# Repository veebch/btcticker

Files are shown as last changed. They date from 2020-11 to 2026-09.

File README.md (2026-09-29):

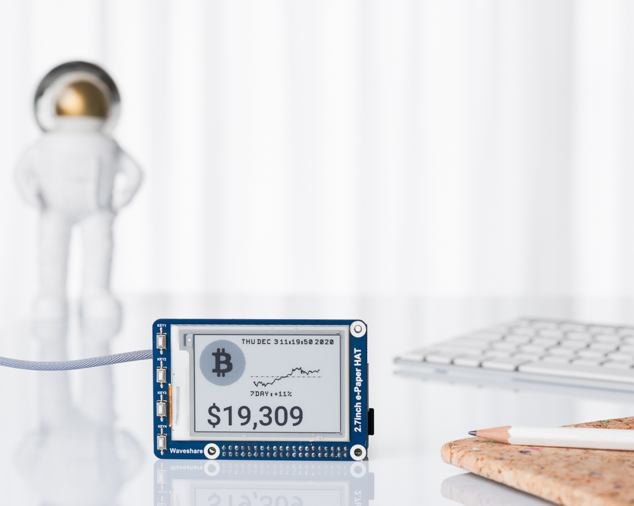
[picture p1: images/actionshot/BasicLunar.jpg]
Action Shot




# Cryptocurrency ePaper Ticker 

**(UPDATE: this all relies on the coingecko free api, and a full OS. If you just want to look at bitcoin prices, we have much simpler devices that involve minimal setup at [dirtboy.industries](https://shop.dirtboy.industries/search/btc))** if you prefer tinkering and/or non BTC stuff, read on...

An ePaper Cryptocurrency price ticker that runs as a Python script on a Raspberry Pi connected to a [Waveshare 2.7 inch monochrome ePaper display](https://www.waveshare.com/wiki/2.7inch_e-Paper_HAT). The script periodically (every 5 mins by default) takes data from CoinGecko and prints a summary to the ePaper. You can specify the exchange used for price info, as well as the currencies that your chosen coin's prices are in. 

A few minutes work gives you a desk ornament that will tastefully and unobtrusively monitor a coin's journey moonward.

(supports all coins/currencies/exchanges listed on [CoinGecko](https://api.coingecko.com/api/v3/coins/list))

# Getting started

## Prerequisites

These instructions work on both older Raspberry Pi OS releases (such as Bullseye) and newer ones (Bookworm, Trixie and later). Newer releases require Python packages installed with `pip` to live in a virtual environment, so the instructions use one on every version. They assume your Raspberry Pi is already connected to the Internet.

If you are using an original Pi Zero or Zero W, use the 32-bit Raspberry Pi OS Lite image (these boards cannot run the 64-bit version). A Zero 2 W can run either, and Lite is still recommended given the 512MB of RAM.

The script is set up to work for the V1 Waveshare 2.7in ePaper. If you are using V2 then see the note in btcticker.py about switching to V2.

If you are running the Pi headless, connect to your Raspberry Pi using `ssh`.

Connect to your ticker over ssh and update and install necessary packages 
```
sudo apt-get update
sudo apt-get install -y git python3-venv
sudo apt-get install -y python3-pil python3-numpy python3-matplotlib python3-spidev python3-gpiozero
sudo apt-get install -y python3-requests python3-babel python3-yaml
```

Enable spi (0=on 1=off)

```
sudo raspi-config nonint do_spi 0
```

Now clone the required software (Waveshare libraries and this script)

```
cd ~
git clone https://github.com/waveshare/e-Paper
git clone https://github.com/veebch/btcticker.git
```
Move to the `btcticker` directory, copy the example config to `config.yaml` and move the required part of the waveshare directory to the `btcticker` directory
```
cd ~/btcticker
cp config_example.yaml config.yaml
cp -r ~/e-Paper/RaspberryPi_JetsonNano/python/lib/waveshare_epd .
rm -rf ~/e-Paper
```

Create a virtual environment inside the `btcticker` directory. The `--system-site-packages` option lets it use the Python packages you just installed with apt (numpy, matplotlib, Pillow, requests, Babel, PyYAML, SPI and GPIO libraries), so pip only needs to install the one module that is not packaged for apt.
```
python3 -m venv --system-site-packages .venv
```
Install the required Python3 modules into the virtual environment
```
.venv/bin/pip install -r requirements.txt
```
You do not need to activate the virtual environment. Running `.venv/bin/python` uses it automatically. To test the ticker by hand:
```
.venv/bin/python btcticker.py
```

## Add Autostart

The command below fills in your own user name and home directory automatically, so it works whatever your user is called.

```
cat <<EOF | sudo tee /etc/systemd/system/btcticker.service
[Unit]
Description=btcticker
Wants=network-online.target
After=network-online.target

[Service]
ExecStart=$HOME/btcticker/.venv/bin/python -u $HOME/btcticker/btcticker.py
WorkingDirectory=$HOME/btcticker/
StandardOutput=inherit
StandardError=inherit
Restart=always
User=$USER

[Install]
WantedBy=multi-user.target
EOF
```
Now enable and start the service you just made
```  
sudo systemctl daemon-reload
sudo systemctl enable --now btcticker.service
```
To check it is running, or to see any errors:
```
systemctl status btcticker.service
journalctl -u btcticker.service -f
```
# Control via buttons

This only applies if you are going to control configuration via the buttons on the board.

The ePaper is slow. There is a lag of a few seconds between button press and a change to the display. 

Here's what each of the buttons do:
- Button 1: Cycle through the cryptocurrencies listed in config.yaml
- Button 2: Rotate Display -90 degrees
- Button 3: Invert Display
- Button 4: Cycle through the fiat currencies listed in config.yaml

Update frequency can be changed in the configuration file (default is 300 seconds).

# Configuration via config file

The file `config.yaml` (the copy of `config_example.yaml` you made earlier) contains a number of options that can be tweaked:

```
display:
  cycle: true # Setting to true makes the ticker cycle through a list of coins
  cyclefiat: true # Setting to true makes fiat cycle too, so you can do multiple pairs
  inverted: false # true for black text on grey, false for grey text
  orientation: 90 # 90 for horizontal display, buttons on left
  trendingmode: false # Add trending coins to those being displayed
  showvolume: false # Show volume (in fiat currency)
  showrank: false # Show ranking (by volume)
  24h: true # true for 24h clock, false for 12h
  locale: en_US # For region specific changes to price formatting
ticker:
  currency: bitcoin,ethereum,cardano # symbols used on coingecko
  exchange: default # specific exchanges can be specified
  fiatcurrency: usd,btc,gbp # 'fiat' currency
  sparklinedays: 1 # Time period shown on sparkline graph
  updatefrequency: 300 # How often price is refreshed (seconds) (lower limit 60s)
```

After changing `config.yaml`, restart the service to pick up the changes:
```
sudo systemctl restart btcticker.service
```

## Values

- **cycle**: switch the display between the listed currencies if set to **true**, display only the first on the list if set to **false**
- **cyclefiat**: cycle listed fiat currencies, display only the first on the list if set to **false**
- **inverted**: Black text on grey background if **false**. Grey text on black background if **true**
- **orientation**: Screen rotation in degrees , can take values **0,90,180,270**
- **trendingmode**: If **true**, it checks the 7 coins that coingecko lists as trending and also displays them (names are included in display)
- **showvolume, showrank**: **true** to include in display, **false** to omit
- **currency**: the coin(s) you would like to display (must be the coingecko id)
- **exchange**: default means use coingecko price, it can also be set to a specific exchange name such as **gdax** (coinbase), **binance** or **kraken** (full list on coingecko api [page](https://www.coingecko.com/api/documentations/v3)) 
- **fiatcurrency**: if **cyclefiat** is set to **True**, it will also cycle, otherwise it will use only the first entry (and cycle with button presses)
- **sparklinedays**: Number of days of historical data appearing on chart
- **updatefrequency**: (in seconds), how often to refresh the display

## Trending mode

When you activate trending mode (by setting to true in the config file, in addition to your coins, the ticker will cycle through 7 coins that are currently listing as trending on CoinGecko (see photo below).

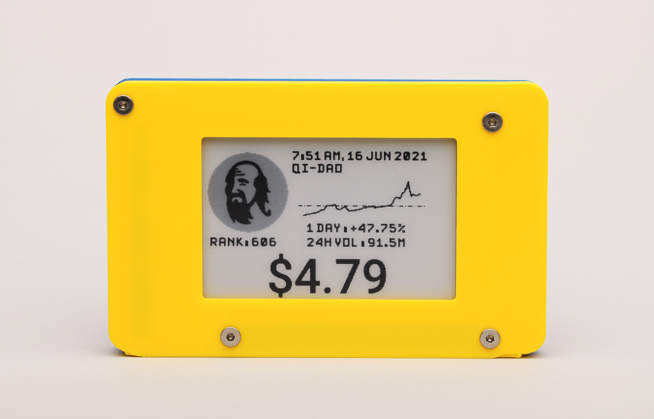
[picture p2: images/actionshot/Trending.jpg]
Action Shot


# Contributing

To contribute, please fork the repository and use a feature branch. Pull requests are welcome.

# Links
Watch the video (https://youtu.be/DNLUmJb7Mj8) 
- Video of the unit working [here](https://youtu.be/DNLUmJb7Mj8)

# Licencing

GNU GENERAL PUBLIC LICENSE Version 3.0

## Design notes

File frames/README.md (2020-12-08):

# Frames

Directory for 3-D files for frames. Get a local 3D printer or CNC machinist to make you something that makes your ticker less naked. 

## Frame v5

Basic frame (that removes access to buttons).

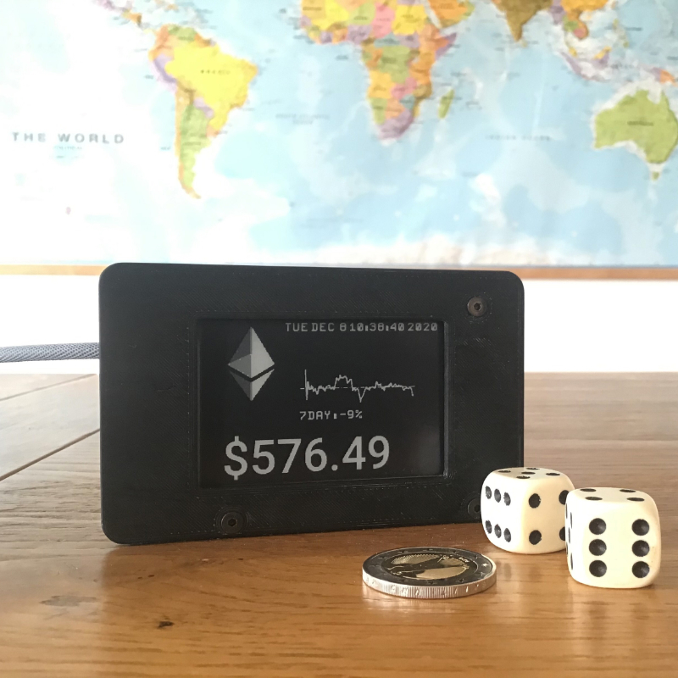
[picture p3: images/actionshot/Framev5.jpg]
Action Shot


- Process: Printed (FDM)
- Material: PC 
- Color: Black
- Quality: Medium
- Post Processing: Light Sanding
(Display set to ```inverted: true``` in config.yaml)

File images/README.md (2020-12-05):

# Image files

currency/ contains 100x100 BMP files that display on the ticker. The filename should match the name in confi.yaml in the root directory, which whould be the name of the coin in the API call

actionshot/ contains images of the thing assembled

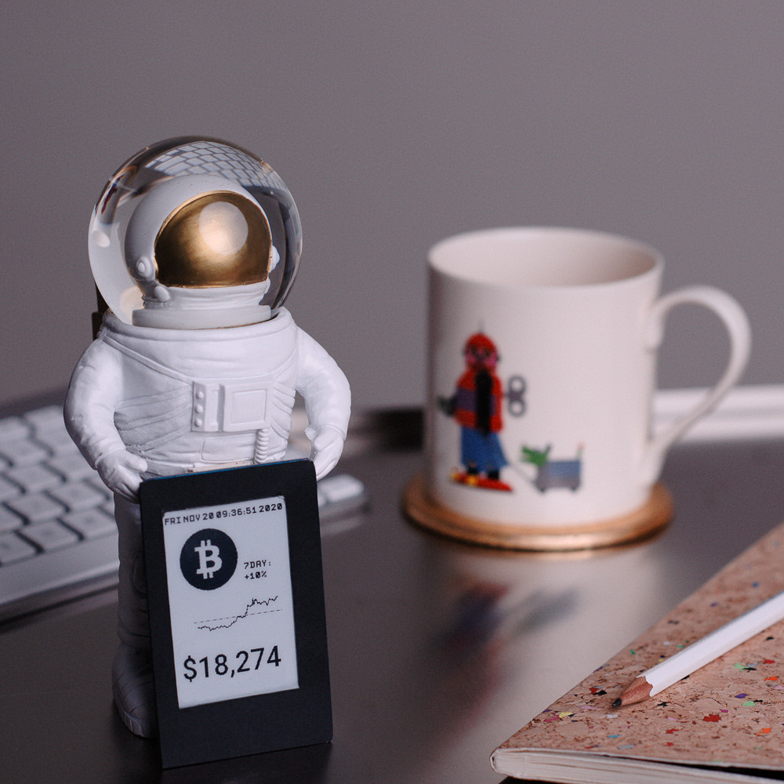
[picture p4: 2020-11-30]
images/actionshot/ANI.jpg

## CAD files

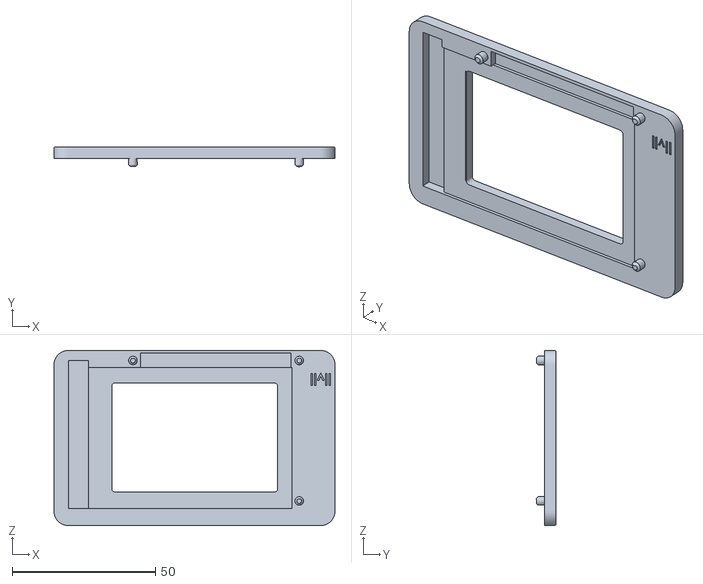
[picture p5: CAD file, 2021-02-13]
frames/Frame v6.stl
98.0 x 7.13 x 61.1

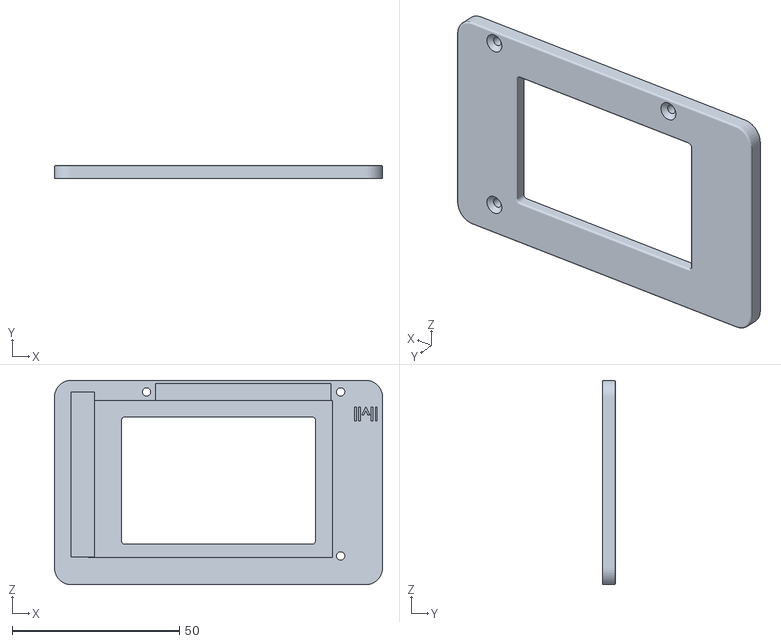
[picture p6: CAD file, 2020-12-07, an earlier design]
frames/Frame v5.stl
98.0 x 4.00 x 61.1

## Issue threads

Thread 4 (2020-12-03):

Unable to run receive error

skydiveguy, 2020-12-03:
Followed all the steps on your githum page. Installed software as directed from Waveshare. Test files from Waveshare display perfectly.

When attempting to run "pyton3 btcticker.py" an error is thrown....

Traceback (most recent call last):
  File "btcticker.py", Line 9, in < module >
    from waveshare_epd import epd2in7
ModuleNotFoundError: No module named 'waveshare_epd'

llvllch, 2020-12-03:
The waveshare_epd must not be installed. The waveshare test ones work because the module files are in the directory structure.

You need to run the setup script for the waveshare module to be installed.
```
e-Paper/RaspberryPi&JetsonNano/python/setup.py install
```

skydiveguy, 2020-12-04:
Negative.

Now I am getting...

Error: error in 'egg_base' option: 'Lib' does not exist or is not a directory

Of course the pip list command does not list the module because it didnt install from the first line.

llvllch, 2020-12-04:
I've just (on a clean Rasbian build) ran

```
cd e-Paper/RaspberryPi&JetsonNano/python
sudo python3 setup.py install
```
and it installed the module.

skydiveguy, 2020-12-04:
Working nowThank you... very strange... I navigated to that same directory before replying but it failed with the message i gave.
Now its working.
Thanks again.

llvllch, 2020-12-04:
Great, I've updated the README to explicitly mention that step. Thanks for finding that wrinkle.

Closed 2020-12-04.

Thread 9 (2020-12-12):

error after approximately 6 hours

jmdeacon, 2020-12-12:
I am using a raspberry pi zero w with the 2.7 screen just as you describe. It runs fine for around 6 hours and then stops working.

The error keeps happening.

Here is a screenshot of the error message.

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

llvllch, 2020-12-12:
That looks like coingekco close the connection. I've not experienced that. Did you change the refresh rate?

I just broadened out the cases where that script falls back to coinapi. Try pulling the latest source and seeing how that behaves after 6h.

jmdeacon, 2020-12-13:
When I first built my ticker, I had changed the config file to refresh every 60 seconds instead of the default 600 seconds. After reading your reply, I decided to switch it back to 600. Now it has been up and running for nearly 24 hours.

Therefore, it appears that the error occurred from trying to refresh every minute. I'm fine with keeping it at every 10 minutes but if anyone else has this problem, you can suggest they go back to every 10 minutes.

llvllch, 2020-12-13:
Great!
I imagine it was the coingecko API.... the change I made to the code should now revert to coinapi in that case. Closing the issue for now.

tmlee, 2020-12-14:
Hey from CoinGecko here, surprised to see how there can be issue if you are only hitting the API once every minute; unless you are somehow making unusually more calls which may be lead to a rate limit problem.

llvllch, 2020-12-14:
It sounds more likely to be an intermittent internet connection. The code currently checks for internet when it starts and then assumes that it is there after that.

@tmlee Out of interest....What is the daily limit for api calls to coingekco?

tmlee, 2020-12-15:
> It sounds more likely to be an intermittent internet connection. The code currently checks for internet when it starts and then assumes that it is there after that.
>
> @tmlee Out of interest....What is the daily limit for api calls to coingekco?

Its currently a minutely limit of 100 requests, but my suggestion is to keep it at 60 calls or less per minute to be absolute safe due to spikes in the public API

llvllch, 2020-12-15:
thanks! The ePaper takes a few seconds to refresh, so the code couldn't exceed that if it tried.

llvllch, 2021-01-04:
> Hey from CoinGecko here, surprised to see how there can be issue if you are only hitting the API once every minute; unless you are somehow making unusually more calls which may be lead to a rate limit problem.

@tmlee Hey.... quick question: Does the coingecko have a way of pulling the price for a specific exchange?

Closed 2020-12-13.

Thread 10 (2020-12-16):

wifi disconnect

snarflakes, 2020-12-16:
I think my wifi shut down randomly, and then it causes btcticker application to shut down because there isn't code to allow it to restart if wifi is lost?

llvllch, 2020-12-16:
Hey :)
It could be that it is the slightly older version that throws an error when the internet goes down. The current version *should* just wait. Pull the latest version and see if it solves the problem.

jmdeacon, 2020-12-16:
I might be having the same or similar problem. Running the latest version.

`INFO:root:Got Historical Data For Last Week from CoinGecko
DEBUG:matplotlib.axes._base:update_title_pos
DEBUG:matplotlib.axes._base:update_title_pos
DEBUG:PIL.PngImagePlugin:STREAM b'IHDR' 16 13
DEBUG:PIL.PngImagePlugin:STREAM b'sBIT' 41 4
DEBUG:PIL.PngImagePlugin:b'sBIT' 41 4 (unknown)
DEBUG:PIL.PngImagePlugin:STREAM b'pHYs' 57 9
DEBUG:PIL.PngImagePlugin:STREAM b'tEXt' 78 57
DEBUG:PIL.PngImagePlugin:STREAM b'IDAT' 147 2125
DEBUG:root:e-Paper busy
DEBUG:root:e-Paper busy release
DEBUG:root:Horizontal
DEBUG:root:e-Paper busy
DEBUG:root:e-Paper busy release
Traceback (most recent call last):
  File "btcticker.py", line 35, in internet
    socket.socket(socket.AF_INET, socket.SOCK_STREAM).connect((host, port))
socket.timeout: timed out

During handling of the above exception, another exception occurred:

Traceback (most recent call last):
  File "btcticker.py", line 325, in <module>
    main()
  File "btcticker.py", line 253, in main
    if internet():
  File "btcticker.py", line 38, in internet
    logging.info("No internet:"+ex)
TypeError: can only concatenate str (not "timeout") to str`

llvllch, 2020-12-16:
Ah.... there has been a change since then ```logging.info("No internet:"+ex)``` is complaining that ex isn't a string.

jmdeacon, 2020-12-16:
Ok, just pulled.

snarflakes, 2020-12-16:
I will pull and recheck! thanks

llvllch, 2020-12-16:
I'll not close until you confirm that it is untroubled by network blips

jmdeacon, 2020-12-16:
It is no longer crashing for me during internet blips.

llvllch, 2020-12-21:
Closing for now..... all is quiet on the netblip front

Closed 2020-12-21.

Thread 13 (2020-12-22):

Error running: python3 -m pip install -r requirements.txt

mjoerck, 2020-12-22:
When I run the command stated in the title I receive an error when building wheels for collected packages: numpy.
I get the following error text back:

````
Failed building wheel for numpy
 Running setup.py clean for numpy
 Complete output from command /usr/bin/python3 -u -c "import setuptools, tokenize;__file__='/tmp/pip-install-tylsvy0g/numpy/setup.py';f=getattr(tokenize, 'open', open)(__file__);code=f.read().replace('\r\n', '\n');f.close();exec(compile(code, __file__, 'exec'))" clean --all:
 Running from numpy source directory.

 `setup.py clean` is not supported, use one of the following instead:

 - `git clean -xdf` (cleans all files)
 - `git clean -Xdf` (cleans all versioned files, doesn't touch
                  files that aren't checked into the git repo)

  Add `--force` to your command to use it anyway if you must (unsupported).
````
Is there a workaround for this, or am I missing something? :)

llvllch, 2020-12-22:
Was this on a fresh install of Rasbian? I've not ran into this one.... hopefully someone who speaks pip better than I do will help.

An alternative is to just install the few dependencies manually

try ```python3 -m pip install numpy``` and see if it still complains

mjoerck, 2020-12-22:
Yes, on a clean install - I will try installing them manually.

mjoerck, 2020-12-22:
Hmm, when I install all the libraries manually and try to run the program using:

`python3 btcticker.py`

I get the following:

```
Traceback (most recent call last):
  File "btcticker.py", line 2, in <module>
    from PIL import Image, ImageOps
  File "/home/pi/.local/lib/python3.7/site-packages/PIL/Image.py", line 94, in <module>
    from . import _imaging as core
ImportError: libopenjp2.so.7: cannot open shared object file: No such file or directory
```

Should I try starting over with fresh install of rasbian again?

llvllch, 2020-12-22:
If that's the quickest thing to do. Some other people have mentioned that they struggled with the Python deps. Maybe some helpful soul will chime in on this thread.

samdogg7, 2020-12-22:
I am having the same issue on a fresh install. I will update if I find a solution.

llvllch, 2020-12-22:
Try on the latest version. Pipreqs seems to have made a bit of a mess. I did a manual rebuild and test

mjoerck, 2020-12-22:
> Try on the latest version. Pipreqs seems to have made a bit of a mess. I did a manual rebuild and test

I did a full reset of the pi and ran:

`python3 -m pip install -r requirements.txt`

without any errors; however, I still get the traceback to line 2... :/

llvllch, 2020-12-22:
Seems odd. Do a ```pip list``` and see what version of Pillow you have

mjoerck, 2020-12-22:
It is running pillow version 6.0.0:

```
pi@raspberrypi:~/btcticker $ pip3 list
Package         Version
--------------- ---------
asn1crypto      0.24.0
certifi         2018.8.24
chardet         3.0.4
cryptography    2.6.1
cycler          0.10.0
entrypoints     0.3
idna            2.6
keyring         17.1.1
keyrings.alt    3.1.1
kiwisolver      1.3.1
matplotlib      3.0.3
nh-currency     1.0.1
numpy           1.16.2
olefile         0.46
Pillow          6.0.0
pip             18.1
pycrypto        2.6.1
PyGObject       3.30.4
pyparsing       2.4.7
python-apt      1.8.4.1
python-dateutil 2.8.1
pyxdg           0.25
PyYAML          5.3.1
requests        2.21.0
RPi.GPIO        0.7.0
SecretStorage   2.3.1
setuptools      40.8.0
six             1.12.0
spidev          3.5
ssh-import-id   5.7
urllib3         1.24.1
waveshare-epd   0.0.0
wheel           0.32.3
```

llvllch, 2020-12-22:
try ```sudo apt-get install libopenjp2-7```

mjoerck, 2020-12-22:
> try `sudo apt-get install libopenjp2-7`

Hooray! It works now, thank you very much!

llvllch, 2020-12-22:
Not too hard, you just need to find an api

mjoerck, 2020-12-22:
> Not too hard, you just need to find an api

Thanks! I'll take a look at it tomorrow. Yahoo has a pretty nice API if you decide to take a look at it yourself. ;) Should I close the issue? I don't really know how this works :P

llvllch, 2020-12-22:
Yeah... I'll close! Good luck with the api.... if it works, don't forget to share :)

Closed 2020-12-22.

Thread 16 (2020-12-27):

Trying to replace functionality of button 4, cannot use it to clear screen

elric25, 2020-12-27:
My use-case means I only have one fiat currency to worry about, so I wanted to use the fourth button to wipe the display clean and stop the program. I took some material from elsewhere in the code as well as some of the e-paper example code provided by the manufacturer, but it doesn't seem to be doing anything

```
if key4state == False:
epd = epd2in7.EPD()
epd.Clear(0xFF)
epd.Sleep()
time.sleep(3)
epd2in7.epdconfig.module_exit()
exit()
```

I can definitely tell that this does stop the program as the display no longer updates and none of the other buttons work, but the screen stays the same with whatever was displayed at the time.

llvllch, 2020-12-27:
It's hard to without seeing your code, but the behaviour you describe is
consistent with an  error crashing the code.

Is the code indented correctly?

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

llvllch, 2020-12-27:
It's hard to without seeing your code, but the behaviour you describe is
consistent with an  error crashing the code.

Is the code indented correctly?

`if key4state == False:
    epd = epd2in7.EPD()
    epd.Clear(0xFF)
    epd.Sleep()
    time.sleep(3)
    epd2in7.epdconfig.module_exit()
    exit()`

elric25, 2020-12-27:
Yeah, the indents are all correct I just didn't copy it in here correctly. When I hit the fourth button I'm not seeing any output in the console, is there another place I might see some information that could help?

llvllch, 2020-12-27:
After you crash it, run from the terminal `python3 btcticker.py` and watch the logging output

elric25, 2020-12-27:
Okay so whenever the screen settles or updates it puts out two debug lines of e-Paper busy and then e-Paper busy release, when I hit the fourth button all I get is another e-Paper busy.

I'm now testing the clearing code with the ctrl + c shutdown command in terminal, still doesn't work and I need to hit ctrl + c twice to actually get out of the logging.

llvllch, 2020-12-27:
My guess (and it is a guess) is that you don't initialise the screen before you send the clear command, so it doesn't clear, but you do have an exit() statement which ends the script.
Try ditching the
`
epd2in7.epdconfig.module_exit()
exit()` and popping an
`epd.Init_4Gray()` before the clear statement.

Closed 2020-12-27.

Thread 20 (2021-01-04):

Fixed crashing problem, fixed connection issue, cleaned up auto scroll feature, and fixed number display

Derpalupagus, 2021-01-04:
1. Fixed the problem with the script being killed on high memory usage because the plot function was not being cleared from memory after displaying the chart.
2. Cleaned up the Auto Scroll feature logic - got rid of updatefrequency since we're now using scrollfrequency to grab data
3. Got rid of the script kill when Coin Gecko is unavailable or no internet.  Now the script will keep trying indefinitely until the connection is good and will not exit the script.
4. Fixed the number display issue; will now display with 2 decimal places unless the value is > 99,999.  Since Coin Gecko returns integers above 10,000, any price > 10,000 will always have zeroes after the decimal.  Prices less than 10,000 will show numbers after the decimal.

This version is stable, been running on a Pi 4 Model B 2GB for a few days now with no problems. Use these these files; rename to btcticker.py and config.yaml and FTP them onto your Raspberry Pi:

[btcticker.py.txt](https://github.com/llvllch/btcticker/files/5763253/btcticker.py.txt)
[config.yaml.txt](https://github.com/llvllch/btcticker/files/5763254/config.yaml.txt)

https://user-images.githubusercontent.com/45051328/103507169-c8825400-4e1b-11eb-9042-ccfaa97d18ee.mp4

Enjoy!

llvllch, 2021-01-04:
Impressive! I will weave these back into the code on the repo. I'd already made some of the changes but I'll take a look at how you handled them to, as there is a good chance you did it better!

Sidenote: That's a fine looking case.

Seeing as this is running stable, I'll close this issue for now.
Again, thanks!

Derpalupagus, 2021-01-04:
Thanks for the feedback - The case will be up on Thingiverse here https://www.thingiverse.com/thing:4709963 in 24 hours, I guess I have to wait a day before it will publish.

Great project!

llvllch, 2021-01-04:
Thanks! I could add the thingiverse link to the frames directory, once it goes live. Is that ok?

Derpalupagus, 2021-01-04:
Absolutely - I also linked this project to the Thing file; sorry I should have asked first.  I can remove it if you want me to.

llvllch, 2021-01-04:
No problem at all!

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

sterdeus, 2021-05-24:
@Derpalupagus Beautiful case. The link to thingiverse is broken. If there any way you share it again? Thank you!

Closed 2021-01-04.

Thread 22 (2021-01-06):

e-paper busy

15rhema, 2021-01-06:
Hi, I followed all the instructions a couple times and I'm getting this line when running btcticker.py:

root@raspberrypi:~/Projects/btcticker# python3 btcticker.py
INFO:root:epd2in7 BTC Frame
INFO:root:{'ticker': {'currency': 'bitcoin,litecoin,bitcoin-cash,ethereum,stellar,monero, uniswap', 'fiatcurrency': 'gbp,usd,eur,jpy,chf', 'updatefrequency': 600}, 'display': {'orientation': 90, 'inverted': True}}
INFO:root:['bitcoin', 'litecoin', 'bitcoin-cash', 'ethereum', 'stellar', 'monero', 'uniswap']
INFO:root:['gbp', 'usd', 'eur', 'jpy', 'chf']
INFO:root:bitcoin
INFO:root:gbp
INFO:root:Getting Data
INFO:root:https://api.coingecko.com/api/v3/coins/markets?vs_currency=gbp&ids=bitcoin
DEBUG:urllib3.connectionpool:Starting new HTTPS connection (1): api.coingecko.com:443
DEBUG:urllib3.connectionpool:https://api.coingecko.com:443 "GET /api/v3/coins/markets?vs_currency=gbp&ids=bitcoin HTTP/1.1" 200 None
INFO:root:Got Live Data From CoinGecko
INFO:root:https://api.coingecko.com/api/v3/coins/bitcoin/market_chart/range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
DEBUG:urllib3.connectionpool:Starting new HTTPS connection (1): api.coingecko.com:443
DEBUG:urllib3.connectionpool:https://api.coingecko.com:443 "GET /api/v3/coins/bitcoin/market_chart/range?vs_currency=gbp&from=1609368509&to=1609973309 HTTP/1.1" 200 None
INFO:root:Got Historical Data For Last Week from CoinGecko
DEBUG:matplotlib.axes._base:update_title_pos
DEBUG:matplotlib.axes._base:update_title_pos
DEBUG:PIL.PngImagePlugin:STREAM b'IHDR' 16 13
DEBUG:PIL.PngImagePlugin:STREAM b'sBIT' 41 4
DEBUG:PIL.PngImagePlugin:b'sBIT' 41 4 (unknown)
DEBUG:PIL.PngImagePlugin:STREAM b'pHYs' 57 9
DEBUG:PIL.PngImagePlugin:STREAM b'tEXt' 78 57
DEBUG:PIL.PngImagePlugin:STREAM b'IDAT' 147 2529
DEBUG:root:e-Paper busy

I did some googling around and it's possible my e-paper is bad? I also tried another fix someone posted by re-compiling the python code for the e-paper but no dice.

llvllch, 2021-01-06:
Does it just hang at that? This is the tail end on of the log on mine after a successful refresh. The 4th line down seems to differ.....

Pretty sure this is a waveshare thing. All the logs for the script (the ones that start with INFO) seem happy...

--snip----

DEBUG:PIL.PngImagePlugin:b'sBIT' 41 4 (unknown)
DEBUG:PIL.PngImagePlugin:STREAM b'pHYs' 57 9
DEBUG:PIL.PngImagePlugin:STREAM b'tEXt' 78 57
DEBUG:PIL.PngImagePlugin:STREAM b'IDAT' 147 1928
 DEBUG:root:e-Paper busy
DEBUG:root:e-Paper busy release
DEBUG:root:Horizontal
DEBUG:root:e-Paper busy
DEBUG:root:e-Paper busy release

15rhema, 2021-01-06:
Yes, it just stays there forever with nothing displayed on the screen. After I changed the python code it displayed this:

DEBUG:root:Forced e-Paper busy release
DEBUG:root:e-Paper busy release
DEBUG:root:Horizontal
DEBUG:root:e-Paper busy
DEBUG:root:Forced e-Paper busy release
DEBUG:root:e-Paper busy release

But I still never get anything on the display.

llvllch, 2021-01-06:
What about the test codes in the example directory on the e-Paper stuff?

I'm of little use on this..... definitely an epaper issue, but I wouldn't know if it is hardware.

llvllch, 2021-01-08:
Something that did occur to me:

Is the screen connection ok? Are the pins in the hat correctly?

15rhema, 2021-01-08:
I haven't had time the last few days to work on this more, but I'm working on testing some demo code on the display to see if I can get that working. Here is a video of my connection.

https://user-images.githubusercontent.com/5685847/104044846-9281fe80-5192-11eb-8cfb-cb5eb9466b34.mp4

llvllch, 2021-01-08:
That looks fine to me. I occasionally misalign the pins, and that has cause the behaviour you describe.

(Nice case)

15rhema, 2021-01-08:
Ok, thanks for the sanity check. I'll have to keep messing around and see if I can get the demo to work. Worst case scenario I'm still in the return window for the e-paper so I could just return and try another one if this one turns out to be bad.

Thanks, the case is still a prototype, it's a remix of another design that I found on thingiverse.  I still need to update the button location.

15rhema, 2021-01-08:
Confirmed that the demo code does the same thing. I guess I'm going to return it. Must be a bad unit. Thanks for your help!

Closed 2021-01-07.

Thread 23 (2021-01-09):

Random crashes - exception

snowboarder04, 2021-01-09:
`DEBUG:root:e-Paper busy
DEBUG:root:e-Paper busy release
INFO:root:No internet
INFO:root:No internet
INFO:root:No internet
INFO:root:No internet
INFO:root:No internet
INFO:root:No internet
INFO:root:Getting Data
INFO:root:https://api.coingecko.com/api/v3/coins/markets?vs_currency=usd&ids=ethereum
DEBUG:urllib3.connectionpool:Starting new HTTPS connection (1): api.coingecko.com:443
DEBUG:urllib3.connectionpool:https://api.coingecko.com:443 "GET /api/v3/coins/markets?vs_currency=usd&ids=ethereum HTTP/1.1" 200 None
INFO:root:Got Live Data From CoinGecko
INFO:root:https://api.coingecko.com/api/v3/coins/ethereum/market_chart/range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
DEBUG:urllib3.connectionpool:Starting new HTTPS connection (1): api.coingecko.com:443
DEBUG:urllib3.connectionpool:https://api.coingecko.com:443 "GET /api/v3/coins/ethereum/market_chart/range?vs_currency=usd&from=1609974311&to=1610233511 HTTP/1.1" 503 None
DEBUG:root:e-Paper busy
DEBUG:root:e-Paper busy release
DEBUG:root:Horizontal
DEBUG:root:e-Paper busy
DEBUG:root:e-Paper busy release
DEBUG:root:spi end
DEBUG:root:close 5V, Module enters 0 power consumption ...
Traceback (most recent call last):
  File "/home/pi/btcticker/btcticker.py", line 208, in fullupdate
    pricestack=getData(config,CURRENCY,FIAT)
  File "/home/pi/btcticker/btcticker.py", line 74, in getData
    rawtimeseries = requests.get(geckourlhistorical).json()
  File "/usr/lib/python3/dist-packages/requests/models.py", line 897, in json
    return complexjson.loads(self.text, **kwargs)
  File "/usr/lib/python3.7/json/__init__.py", line 348, in loads
    return _default_decoder.decode(s)
  File "/usr/lib/python3.7/json/decoder.py", line 337, in decode
    obj, end = self.raw_decode(s, idx=_w(s, 0).end())
  File "/usr/lib/python3.7/json/decoder.py", line 355, in raw_decode
    raise JSONDecodeError("Expecting value", s, err.value) from None
json.decoder.JSONDecodeError: Expecting value: line 1 column 1 (char 0)

During handling of the above exception, another exception occurred:

Traceback (most recent call last):
  File "/home/pi/btcticker/btcticker.py", line 316, in <module>
    main()
  File "/home/pi/btcticker/btcticker.py", line 302, in main
    lastcoinfetch=fullupdate()
  File "/home/pi/btcticker/btcticker.py", line 216, in fullupdate
    sleep(10)
NameError: name 'sleep' is not defined`

Config:

`display:
  inverted: false
  orientation: 180
ticker:
  currency: ethereum,bitcoin,bitcoin-cash
  exchange: default
  fiatcurrency: usd,gbp
  sparklinedays: 3
  updatefrequency: 60`

Note: Those `INFO:root:No internet` messages are false, the device does have internet

llvllch, 2021-01-10:
Hey Rob.... the first thing to try is using the latest version, This is
from memory because the code isn't in front of me, but line 216 does not
say 'sleep(10)' in the latest version.

The error aboit
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

llvllch, 2021-01-10:
Yep..... you're on an older version. Do a `git pull` from the directory the script is in and try again

snowboarder04, 2021-01-10:
Thanks, will give that a go

snowboarder04, 2021-01-10:
Since pulling the latest it's been stable. I reckon I must've typo'd somewhere while reviewing the source. I've closed this one out and thanks for the great project!

Closed 2021-01-10.

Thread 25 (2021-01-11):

"No internet" leading to "Coingecko is unreachable: Exit the script"

snarflakes, 2021-01-11:
Despite updating, I keep getting INFO: No internet x 2, which then eventually reconnects, gets data from coingecko, and then on the next refresh hits "No internet" x 1,  then "getting data," and then at some point during getting data from coingecko leads to "Coingecko is unreachable - Exit the script."
Problem: During times of weak wifi, or internet blips occuring during the coingecko data retrieval stage, coingecko data loss or interruption leads to shut down of program instead of reattempting.  This has been occuring once every 2 days.
Solution: Do we need to add in another pause somewhere during the coingecko data grab? Or perhaps a Re-attempt if there was a disruption during coingecko download so the program doesn't shut down when hitting this challenge?

llvllch, 2021-01-11:
The current version should just wait 10 seconds and try again if the
coingecko pull fails. This should also happen if an exception is thrown mid
pull. I'll have another look at the code. I think my use of systemd might
be stopping me from seeing it.

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

snarflakes, 2021-01-12:
I will pull again, to retest in case I missed an update.

llvllch, 2021-01-13:
If connection drops, a holding screen should display until connection is
re-established. Let me know how you get on….

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

snarflakes, 2021-01-15:
Thanks,
The problem has changed since the last pull. I’m checking frequency pattern and to make sure it is repeating exactly the same errors. I will update in a few days.

Sent from ProtonMail Mobile

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

snarflakes, 2021-01-15:
Okay this error repeated x2 now.  Re-occurring every 1-2 days. Since I pulled your last changes per my previous comment this is occurring.  The old problem which said Coingecko is unreachable - Exit the script doesn't seem to be occurring any more.

This is what is happening now:

I see one: INFO:root: No internet
it moves forward no issues and getting data
Then it goes

DEBUG:root:spi end
DEBUG:root: close 5V, module enteres 0 power consumptions...
Trace back (most recent call last):
File "btc ticker.pay", line 316 n <module>
Main()
File "btc ticker.pay", line 271, in main
Key1state = GPIO.input(key1)
RuntimeError: please set pin numbering mode using GPIO.setmode(GPIO.BOARD or GPIO.setmode(GPIO.BCM)

The pi screen displays your little Axie, when this has happened. Screen still detached and accessible.

Is a reboot occurring? I haven't seen the error happen live, I just find the pi in this state.

llvllch, 2021-01-15:
what is File “btc ticker.pay”? Or is that just some typos that appears
during cut and paste. It looks like pressing key 4 is throwing that error,
I’ll try to reproduce.

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

snarflakes, 2021-01-15:
sorry autocorrect.  Should read .py

llvllch, 2021-02-10:
Closing for now. No news is good news :)

SR00000, 2021-02-20:
I wanted to comment on this because I had this problem earlier and found the issue. My internet gateway had "advanced security" enabled and it automatically blocked outgoing pings from my Pi because it thought it was trying to DDOS another network. You have to disable that advanced/smart security you may have enabled on your modem/gateway.

If you're able to use the command "curl -X GET https://api.coingecko.com/api/v3/exchanges" and get a screen full of text, that means its definitely been disabled from your modems end. Good luck!

Closed 2021-02-10.

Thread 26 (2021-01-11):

Crash with GPIO error

DigiDr, 2021-01-11:
```
DEBUG:root:e-Paper busy release
INFO:root:Getting Data
INFO:root:https://api.coingecko.com/api/v3/coins/markets?vs_currency=usd&ids=bitcoin
DEBUG:urllib3.connectionpool:Starting new HTTPS connection (1): api.coingecko.com:443
DEBUG:urllib3.connectionpool:https://api.coingecko.com:443 "GET /api/v3/coins/markets?vs_currency=usd&ids=bitcoin HTTP/1.1" 200 None
INFO:root:Got Live Data From CoinGecko
INFO:root:https://api.coingecko.com/api/v3/coins/bitcoin/market_chart/range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
DEBUG:urllib3.connectionpool:Starting new HTTPS connection (1): api.coingecko.com:443
DEBUG:urllib3.connectionpool:https://api.coingecko.com:443 "GET /api/v3/coins/bitcoin/market_chart/range?vs_currency=usd&from=1609945864&to=1610205064 HTTP/1.1" 200 None
INFO:root:Got price for the last 3 days from CoinGecko
DEBUG:root:e-Paper busy
DEBUG:root:e-Paper busy release
DEBUG:root:Horizontal
DEBUG:root:e-Paper busy
DEBUG:root:e-Paper busy release
DEBUG:root:spi end
DEBUG:root:close 5V, Module enters 0 power consumption ...
Traceback (most recent call last):
  File "btcticker.py", line 316, in <module>
    main()
  File "btcticker.py", line 271, in main
    key1state = GPIO.input(key1)
RuntimeError: Please set pin numbering mode using GPIO.setmode(GPIO.BOARD) or GPIO.setmode(GPIO.BCM)
```

DigiDr, 2021-01-11:
To be clear, this happened randomly and without any input from me at the time.

llvllch, 2021-01-11:
I've not seen that one before. Looks like the GPIO module doesn't like that command. Could it be your version of the module?

DigiDr, 2021-01-11:
I don't think so, it's been working perfectly up and until now. Perhaps there is a bug at a lower level?

llvllch, 2021-01-11:
It;s sufficiently odd that I'd do a clean install... that said, someone more knowledgeable may chip in with an actual solution :)

DigiDr, 2021-01-13:
Had this again today quite randomly after 48 hours of everything running smoothly. Hmm

llvllch, 2021-01-13:
same thing in the logs?

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

DigiDr, 2021-01-13:
Yes

llvllch, 2021-01-13:
The lines
    DEBUG:root:spi end
    DEBUG:root:close 5V, Module enters 0 power consumption ...
Aren't being triggered by this script. That's the waveshare module. I'd see if there is anything about spontaneous sleep on their documentation. The other thing I'd try is another power supply for the pi. In my experience, weird problems almost always come down to cables and/or power

llvllch, 2021-01-24:
Closing for now. I've not been able to reproduce the error.

Closed 2021-01-24.

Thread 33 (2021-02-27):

GPIO Error

manuelautomatisch, 2021-02-27:
Traceback (most recent call last):
File "btcticker.py", line 362, in <module>
main()
File "btcticker.py", line 316, in main
key1state = GPIO.input(key1)
RuntimeError: Please set pin numbering mode using GPIO.setmode(GPIO.BOARD) or GPIO.setmode(GPIO.BCM)

dkim777, 2021-02-28:
Getting exact error message on new one I just installed.

I wasn't getting this error on one I built two weeks ago though.
only difference is SD card size  32GB vs 12GB(doesn't work)

llvllch, 2021-02-28:
Looks like the GPIO module complaining. Is the script not working or is it complaining when closed?

I can't reproduce the error. What does your
      python3 -m pip list
show for the module RPi.GPIO?

manuelautomatisch, 2021-02-28:
Its also a new error for me.

Thats the output from **python3 -m pip list**

Package           Version
----------------- -----------
asn1crypto        0.24.0
astroid           2.1.0
asttokens         1.1.13
automationhat     0.2.0
beautifulsoup4    4.7.1
blinker           1.4
blinkt            0.1.2
buttonshim        0.0.2
Cap1xxx           0.1.3
certifi           2018.8.24
chardet           3.0.4
Click             7.0
colorama          0.3.7
colorzero         1.1
cookies           2.2.1
cryptography      2.6.1
cupshelpers       1.0
cycler            0.10.0
docutils          0.14
drumhat           0.1.0
entrypoints       0.3
envirophat        1.0.0
ExplorerHAT       0.4.2
Flask             1.0.2
fourletterphat    0.1.0
gpiozero          1.5.1
html5lib          1.0.1
idna              2.6
isort             4.3.4
itsdangerous      0.24
jedi              0.13.2
Jinja2            2.10
keyring           17.1.1
keyrings.alt      3.1.1
kiwisolver        1.3.1
lazy-object-proxy 1.3.1
logilab-common    1.4.2
lxml              4.3.2
MarkupSafe        1.1.0
matplotlib        3.3.4
mccabe            0.6.1
microdotphat      0.2.1
mote              0.0.4
motephat          0.0.3
mypy              0.670
mypy-extensions   0.4.1
nh-currency       1.0.1
numpy             1.16.2
oauthlib          2.1.0
olefile           0.46
pantilthat        0.0.7
parso             0.3.1
pexpect           4.6.0
pgzero            1.2
phatbeat          0.1.1
pianohat          0.1.0
picamera          1.13
piglow            1.2.5
pigpio            1.44
Pillow            8.1.0
pip               18.1
psutil            5.5.1
pycairo           1.16.2
pycrypto          2.6.1
pycups            1.9.73
pygame            1.9.4.post1
Pygments          2.3.1
PyGObject         3.30.4
pyinotify         0.9.6
PyJWT             1.7.0
pylint            2.2.2
pyOpenSSL         19.0.0
pyparsing         2.4.7
pyserial          3.4
pysmbc            1.0.15.6
python-apt        1.8.4.3
python-dateutil   2.8.1
pyxdg             0.25
PyYAML            5.4.1
rainbowhat        0.1.0
reportlab         3.5.13
requests          2.21.0
requests-oauthlib 1.0.0
responses         0.9.0
roman             2.0.0
**RPi.GPIO          0.7.0    <-------**
RTIMULib          7.2.1
scrollphat        0.0.7
scrollphathd      1.2.1
SecretStorage     2.3.1
Send2Trash        1.5.0
sense-hat         2.2.0
setuptools        40.8.0
simplejson        3.16.0
six               1.12.0
skywriter         0.0.7
sn3218            1.2.7
soupsieve         1.8
spidev            3.4
ssh-import-id     5.7
thonny            3.3.0
touchphat         0.0.1
twython           3.7.0
typed-ast         1.3.1
unicornhathd      0.0.4
urllib3           1.24.1
waveshare-epd     0.0.0
webencodings      0.5.1
Werkzeug          0.14.1
wheel             0.32.3
wrapt             1.10.11

llvllch, 2021-02-28:
Interesting. I'm on 0.6.5.

Try
`python3 -m pip install --force-reinstall RPi.GPIO==0.6.5`

It looks like it is a bug in RPi.GPIO in that the line it is complaining about is actually in the script.

manuelautomatisch, 2021-02-28:
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

llvllch, 2021-02-28:
I have RPi.GPIO version 0.6.5..... try downgrading to that

manuelautomatisch, 2021-02-28:
Okay, I tried it but the same error pops up again

llvllch, 2021-02-28:
I added a cleanup line to the exit of the code, perhaps that helps? Try it on the latest version.

manuelautomatisch, 2021-02-28:
Okay, I'll try

manuelautomatisch, 2021-02-28:
No seems not to work, same error again.

DEBUG:root:spi end
DEBUG:root:close 5V, Module enters 0 power consumption ...
Traceback (most recent call last):
  File "btcticker.py", line 364, in <module>
    main()
  File "btcticker.py", line 317, in main
    key1state = GPIO.input(key1)
RuntimeError: Please set pin numbering mode using GPIO.setmode(GPIO.BOARD) or GPIO.setmode(GPIO.BCM)

llvllch, 2021-02-28:
Given that I can't reproduce, and that script does set pin numbering mode (line 298), I'd either raise it with a RPi.GPIO forum and/or do a clean install.

Unless anyone else can see the issue?

manuelautomatisch, 2021-02-28:
Okay, thank you anyway. I will see what im doing

llvllch, 2021-02-28:
I'll leave it open in the hope that someone else has the answer :)

manuelautomatisch, 2021-02-28:
okay, thx :)

llvllch, 2021-02-28:
Found it!

Latest pull will fix it

dkim777, 2021-02-28:
Latest code works for me, thanks!
by the way my RPi.GPIO is also 0.7.0

manuelautomatisch, 2021-03-01:
Ah nice, latest code works for me too. Thank you very much :)

Closed 2021-03-01.

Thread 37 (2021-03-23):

Crash after too many reload cycles

lukma99, 2021-03-23:
I have to restart the script every few days, because it crashes. Down here you can see the last lines of the log. It seems that an image is loaded too often and not closed properly.

```
INFO:root:Got price for the last 7 days from CoinGecko
DEBUG:PIL.PngImagePlugin:STREAM b'IHDR' 16 13
DEBUG:PIL.PngImagePlugin:STREAM b'tEXt' 41 57
DEBUG:PIL.PngImagePlugin:STREAM b'pHYs' 110 9
DEBUG:PIL.PngImagePlugin:STREAM b'IDAT' 131 3226
INFO:root:Getting token Image from Image directory
INFO:root:[Errno 24] Too many open files: '/home/pi/btcticker-main_19032021/images/thebean.bmp'
```

llvllch, 2021-03-23:
This would explain the occasional out of memory message that people have been getting. I've just updated the code to close stuff after use.

Pull the latest version and see if it helps.

lukma99, 2021-03-23:
On startup:

```
INFO:root:Getting token Image from Image directory
DEBUG:root:e-Paper busy
DEBUG:root:e-Paper busy release
DEBUG:root:Horizontal
DEBUG:root:e-Paper busy
DEBUG:root:e-Paper busy release
DEBUG:PIL.Image:Error closing: 'Image' object has no attribute 'fp'
DEBUG:root:spi end
DEBUG:root:close 5V, Module enters 0 power consumption ...
Traceback (most recent call last):
  File "btcticker.py", line 370, in <module>
    main()
  File "btcticker.py", line 323, in main
    key1state = GPIO.input(key1)
RuntimeError: Please set pin numbering mode using GPIO.setmode(GPIO.BOARD) or GPIO.setmode(GPIO.BCM)
```

GPIO error is new. I had it in an older version as well but you fixed it a few weeks ago.

llvllch, 2021-03-23:
The epd sleep was the culprit. I've commented it out. I will add it back in a way that doesn't cause the bug. I think it is healthier for the epaper to snooze between updates

lukma99, 2021-03-24:
Now it doesn't crash, but it still gives this error at the end of every cycle:
```
DEBUG:PIL.Image:Error closing: 'Image' object has no attribute 'fp'
```

llvllch, 2021-03-24:
So my blanket application of image closes may have been overkill :) Updated!

lukma99, 2021-03-24:
No more error messages! I will leave it running for a week and close the issue, if it is really solved :)

llvllch, 2021-03-24:
Promising! Fingers crossed this works!

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

llvllch, 2021-03-26:
I just updated slightly, saving the screen image appears to do the garbage collection that avoids out of memory errors

zerzer04, 2021-03-29:
Im having the same issue as well.

Tried this approach with "deepcopy": https://stackoverflow.com/questions/29234413/too-many-open-files-error-when-opening-and-loading-images-in-pillow

Also will run it for a while to see if it worked out

lukma99, 2021-04-01:
Update: It still crashes after some time. But this time without a warning. Just `Killed`. Is it the same for you @zerzer04 ?
I have set the refresh rate to 1 minute to test it quicker. Works for approximately half a day and then I have to restart the script everytime.

Last lines of log before exit:
```
INFO:root:Got Live Data From CoinGecko
INFO:root:https://api.coingecko.com/api/v3/coins/bitcoin/market_chart/range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
DEBUG:urllib3.connectionpool:Starting new HTTPS connection (1): api.coingecko.com:443
DEBUG:urllib3.connectionpool:https://api.coingecko.com:443 "GET /api/v3/coins/bitcoin/market_chart/range?vs_currency=eur&from=1616627049&to=1617231849 HTTP/1.1" 200 None
INFO:root:Got price for the last 7 days from CoinGecko
DEBUG:PIL.PngImagePlugin:STREAM b'IHDR' 16 13
DEBUG:PIL.PngImagePlugin:STREAM b'tEXt' 41 57
DEBUG:PIL.PngImagePlugin:STREAM b'pHYs' 110 9
DEBUG:PIL.PngImagePlugin:STREAM b'IDAT' 131 2336
Killed
```

llvllch, 2021-04-01:
This sounds like it is being killed for using too much memory. If you run 'top' to monitor the process, you should be able to see whether it is getting bloated.

zerzer04, 2021-04-01:
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

For me its working stable for 3 days already. Only changes to the code I made is replacing any "Image.open(file)" with "copy.deepcopy(Image.open(file))"...

llvllch, 2021-04-01:
It looks like PIL is the bit that is pushing it to the point where it is killed

lukma99, 2021-04-01:
Will try the same with deepcopy

llvllch, 2021-04-01:
I've also just updated with some manual cleanup of variables PIL uses. If that doesn't work, I'd guess it's a PIL issue. Using systemd to restart the script if it is killed will take care of things.

Morgawr, 2021-04-01:
I've definitely had issues running the script in the last few days as it keeps thrashing my SD card due to hitting swap (it actually ended up killing one of the SD cards I had before I realized what was going on). I noticed with default settings I couldn't keep it on for longer than 1 day as the PI would just OOM and freeze and I'd have to restart.

Right now I just "fixed" the issue with a quick workaround: removed the while loop in the python script and just ran a while loop in bash instead that opens the python script for 1 single run and then automatically quits, but obviously with this solution the buttons don't really work.

I'll probably take a deeper look when I have more time if it isn't solved by then 👍

lukma99, 2021-04-02:
Getting this error when running `dmesg -T| grep -E -i -B100 'killed process'`:
```
[Fri Apr  2 03:48:15 2021] oom-kill:constraint=CONSTRAINT_NONE,nodemask=(null),cpuset=/,mems_allowed=0,global_oom,task_memcg=/,task=python3,pid=22314,uid=1000
[Fri Apr  2 03:48:15 2021] Out of memory: Killed process 22314 (python3) total-vm:988808kB, anon-rss:873956kB, file-rss:0kB, shmem-rss:0kB, UID:1000 pgtables:976kB oom_score_adj:0
```

Don't know if it is my system now or a common thing :/

zerzer04, 2021-04-02:
actually, the issue seem not with Pillow at all, but with display file descriptor.

lsof -p <python pid> will show that each time the refresh happens, the script opens a new /dev/spidev0.0 file descriptor and doesn't close it

this is caused by "epd.Init_4Gray()" being called all the time prior to screen updates

calling epd.Init_4Gray() only once right before "while" loop seem solve the issue.

Im running now the script again with refresh rate 30sec to test this

**And Pillow actually closes files after Image.Open, so no issue there

llvllch, 2021-04-02:
I've moved the initialization out of the loop. Thanks!

Closed 2021-04-06.

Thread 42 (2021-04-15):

python3 -m pip install -r requirements.txt

flyingmonkey12, 2021-04-15:
Hello all, I am running a fresh install of Rasbian on Pi Zero W and using waveshare 2.7in e-paper HAT. Whenever I run "python3 -m pip install -r requirements.txt", it throw me this error:

`  Failed building wheel for numpy `
`  Running setup.py clean for numpy `
`  Complete output from command /usr/bin/python3 -u -c "import setuptools, tokeni        ze;__file__='/tmp/pip-install-hecy4lsy/numpy/setup.py';f=getattr(tokenize, 'open        ', open)(__file__);code=f.read().replace('\r\n', '\n');f.close();exec(compile(co        de, __file__, 'exec'))" clean --all:`
`  Running from numpy source directory.`
`
  `setup.py clean` is not supported, use one of the following instead:`

    - `git clean -xdf` (cleans all files)
    - `git clean -Xdf` (cleans all versioned files, doesn't touch
                        files that aren't checked into the git repo)
`
`  Add `--force` to your command to use it anyway if you must (unsupported).`
`

1. I have tried using full Rasbian
2. I have followed and installed everything I could google.
3. I started over so many times
4. pi@raspberrypi:~ $ pip3 list
Package         Version
--------------- ---------
asn1crypto      0.24.0
certifi         2018.8.24
chardet         3.0.4
cryptography    2.6.1
cycler          0.10.0
Cython          0.29.23
entrypoints     0.3
idna            2.6
Jetson.GPIO     2.0.16
keyring         17.1.1
keyrings.alt    3.1.1
kiwisolver      1.3.1
matplotlib      3.4.1
nh-currency     1.0.1
numpy           1.20.2
olefile         0.46
Pillow          8.2.0
pip             18.1
pycrypto        2.6.1
PyGObject       3.30.4
pyparsing       2.4.7
python-apt      1.8.4.3
python-dateutil 2.8.1
pyxdg           0.25
PyYAML          5.4.1
requests        2.12.4
RPi.GPIO        0.7.0
SecretStorage   2.3.1
setuptools      40.8.0
six             1.12.0
spidev          3.5
ssh-import-id   5.7
urllib3         1.24.1
waveshare-epd   0.0.0
wheel           0.32.3

5. when I run python3 btcticker.py, I get following
pi@raspberrypi:~/btcticker $ python3 btcticker.py
Traceback (most recent call last):
  File "btcticker.py", line 9, in <module>
    import RPi.GPIO as GPIO
  File "/usr/local/lib/python3.7/dist-packages/RPi/GPIO/__init__.py", line 1, in <module>
    from Jetson.GPIO import *
  File "/usr/local/lib/python3.7/dist-packages/Jetson/GPIO/__init__.py", line 1, in <module>
    from .gpio import *
  File "/usr/local/lib/python3.7/dist-packages/Jetson/GPIO/gpio.py", line 70, in <module>
    model, JETSON_INFO, _channel_data_by_mode = gpio_pin_data.get_data()
  File "/usr/local/lib/python3.7/dist-packages/Jetson/GPIO/gpio_pin_data.py", line 438, in get_data
    raise Exception('Could not determine Jetson model')
Exception: Could not determine Jetson model

6. I also read this link: <https://github.com/llvllch/btcticker/issues/13>

Can someone help me troubleshoot this?  What am I missing?

llvllch, 2021-04-15:
That looks like you've installed the Jetson version of the GPIO module (See the messages in #5 on your list). If you revisit the waveshare install, you might have some joy

flyingmonkey12, 2021-04-15:
1. so I went to waveshare's github from their Demo code: https://github.com/waveshare/e-Paper
2. then, I downloaded their "RaspberryPi_JetsonNano"
3. I used their instruction from their pdf: <https://www.waveshare.com/w/upload/3/31/2.7inch_e-paper_hat_user_manual_en.pdf>
4. I did everything from page 13 to page 15.  But, I didn't run anything listed below WIRINGPI LIBRARY and PYTHON2 LIBRARY. I assumed I just need PYTHON3... so I ran everything under that...
6. I ran sudo pip3 install RPi.GPIO, it says
Looking in indexes: https://pypi.org/simple, https://www.piwheels.org/simple
Requirement already satisfied: RPi.GPIO in /usr/local/lib/python3.7/dist-packages (0.7.0)

I know I must done something wrong, but I have no clue what is it that I am missing...? Sorry I am 2 days old with python experience...

llvllch, 2021-04-15:
looks fine! It is just saying you already have RPi.GPIO.... keep going :)

On Thu, 15 Apr 2021 at 21:37, flyingmonkey12 ***@***.***>
wrote:

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

flyingmonkey12, 2021-04-15:
pi@raspberrypi:~/btcticker $ python3 btcticker.py
Traceback (most recent call last):
  File "btcticker.py", line 9, in <module>
    import RPi.GPIO as GPIO
  File "/usr/local/lib/python3.7/dist-packages/RPi/GPIO/__init__.py", line 1, in <module>
    from Jetson.GPIO import *
  File "/usr/local/lib/python3.7/dist-packages/Jetson/GPIO/__init__.py", line 1, in <module>
    from .gpio import *
  File "/usr/local/lib/python3.7/dist-packages/Jetson/GPIO/gpio.py", line 70, in <module>
    model, JETSON_INFO, _channel_data_by_mode = gpio_pin_data.get_data()
  File "/usr/local/lib/python3.7/dist-packages/Jetson/GPIO/gpio_pin_data.py", line 438, in get_data
    raise Exception('Could not determine Jetson model')
Exception: Could not determine Jetson model

llvllch, 2021-04-15:
looks like the jetson version is still there... could you restart from a
clean image?

On Thu, 15 Apr 2021 at 22:18, flyingmonkey12 ***@***.***>
wrote:

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

flyingmonkey12, 2021-04-15:
not sure if I need to be concerned...
so I ran from fresh image, while sudo tar zxvf bcm2835-1.xx.tar.gz, then extract, then configure, then "make", I get the following:
pi@raspberrypi:~/pi/bcm2835-1.68 $ make
make  all-recursive
make[1]: Entering directory '/home/pi/pi/bcm2835-1.68'
Making all in src
make[2]: Entering directory '/home/pi/pi/bcm2835-1.68/src'
gcc -DHAVE_CONFIG_H -I. -I..     -g -O2 -MT bcm2835.o -MD -MP -MF .deps/bcm2835.Tpo -c -o bcm2835.o bcm2835.c
bcm2835.c:1945:1: fatal error: opening dependency file .deps/bcm2835.Tpo: Permission denied
 }
 ^
compilation terminated.
make[2]: *** [Makefile:567: bcm2835.o] Error 1
make[2]: Leaving directory '/home/pi/pi/bcm2835-1.68/src'
make[1]: *** [Makefile:365: all-recursive] Error 1
make[1]: Leaving directory '/home/pi/pi/bcm2835-1.68'
make: *** [Makefile:306: all] Error 2

llvllch, 2021-04-16:
The waveshare instructions tell you to run 'sudo make' :)

flyingmonkey12, 2021-04-16:
(ಥ﹏ಥ)  I promise you the pdf didn't say "sudo make" on page 14: https://www.waveshare.com/w/upload/3/31/2.7inch_e-paper_hat_user_manual_en.pdf

so I started from scratch clean Pi lite and I did the following:
sudo apt-get update
sudo apt-get upgrade
sudo apt install git
sudo apt install screen

sudo cp -r /boot/RaspberryPi/ ./
sudo chmod 777 -R RaspberryPi/
sudo tar zxvf bcm2835-1.68.tar.gz
cd bcm2835-1.68
sudo ./configure
sudo make
sudo make check
sudo make install

sudo apt-get install python3-pip
sudo apt-get install python3-pil
sudo pip3 install spidev
sudo pip3 install RPi.GPIO
sudo pip3 install Pillow
sudo pip3 install nh-currency
sudo apt-get install python3-numpy

sudo apt-get install libopenjp2-7
sudo apt-get install libqt5gui5
sudo apt-get install python-scipy
sudo apt install libatlas-base-dev

cd e-Paper/RaspberryPi_JetsonNano/python
sudo python3 setup.py install
cd ~
git clone https://github.com/llvllch/btcticker.git
cd btcticker
python3 -m pip install -r requirements.txt
screen bash
python3 btcticker.py

pi@raspberrypi:~/btcticker $ python3 btcticker.py
Traceback (most recent call last):
  File "btcticker.py", line 364, in <module>
    main()
  File "btcticker.py", line 296, in main
    epd.Init_4Gray()
  File "/usr/local/lib/python3.7/dist-packages/waveshare_epd-0.0.0-py3.7.egg/waveshare_epd/epd2in7.py", line 295, in Init_4Gray
    if (epdconfig.module_init() != 0):
  File "/usr/local/lib/python3.7/dist-packages/waveshare_epd-0.0.0-py3.7.egg/waveshare_epd/epdconfig.py", line 74, in module_init
    self.SPI.open(0, 0)
FileNotFoundError: [Errno 2] No such file or directory

llvllch, 2021-04-16:
Did you enable SPI?

flyingmonkey12, 2021-04-16:
(づ｡◕‿‿◕｡)づ omg!!  this is my first time seeing the screen actually works!!!  I am now too scared to power it off, it is looking so pretty.
Thank you so much, I will give you a hug if I physically can!!
One more question: does this ticker just automatically run the "python3 btcticker.py" on power up?
I am building this little thing for my grandpa, he has invested into some btc. I doubt he knows how to ssh.

llvllch, 2021-04-16:
Hooray! To make it run on power up, I used systemctrl. You can also use
cronjobs…..

On Fri, 16 Apr 2021 at 16:47, flyingmonkey12 ***@***.***>
wrote:

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

flyingmonkey12, 2021-04-16:
I have unplugged it from outlet power and had it plugged to my laptop USB. It is alive and working!
sudo nano /etc/rc.local
add below line above exit0
sudo -u pi /usr/bin/python3 /home/pi/btcticker/btcticker.py &
ctrl + x
Y
Enter
it now auto-magically runs when powering on.  Thanks for all your help!!

llvllch, 2021-04-17:
Bravo! Your grandad will be pleased!

On Sat, 17 Apr 2021 at 01:51, flyingmonkey12 ***@***.***>
wrote:

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

Closed 2021-04-16.

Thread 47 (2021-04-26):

IDEA: Speed up the display.

RattyDAVE, 2021-04-26:
the writing to the display is a bit slow. (Well way more than a bit)

This module https://github.com/elad661/rpi_epd2in7 has a much quicker write method.

llvllch, 2021-04-26:
That's a good idea.

I vaguely recall that tried this one, thinking the partial refresh would a better way to do it. In the end I opted for the 'official' waveshare module due to the lack of activity on that module.

NeilInnes, 2021-06-15:
Thoughts on this module @llvllch https://github.com/MarvelousBlack/rpi_epaper ?

Happy to give it a whirl if this module seem ok to you 😄

llvllch, 2021-06-15:
Yes please. I'm going to add a bit of backoff retry logic to the data pull.
Coingecko seems to throttle during times of high traffic, so I'll try to
make the data pull a little more mindful of that

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

NeilInnes, 2021-06-15:
Cool - got it working last night to use this library - partial update for this screen (according to the library) only supports a max area of 255x255 so will need quite a refactor to do this. Leave it with me 😄

RattyDAVE, 2021-06-15:
I have been looking at this. https://github.com/pskowronek/epaper-clock-and-more/tree/master/epds

This is changes the timings so quicker. About 10x quicker on Black and white screen.

NeilInnes, 2021-06-15:
I like the backoff idea - this could be:
- Move all the API calls are moved to a central new method
- The method could try the request and on fail (HTTP code, timeout or message):
  - sleep (attempt count * 5 seconds?)
  - Retry (recursively call itself)
  - Increase a retry count variable (passed recursively + 1)
  - On reaching maximum number of retries, return an error (as current functionality)

NeilInnes, 2021-06-15:
> I have been looking at this. https://github.com/pskowronek/epaper-clock-and-more/tree/master/epds
>
> This is changes the timings so quicker. About 10x quicker on Black and white screen.

That appears to use FAST mode - from other projects I've read `using fast mode may make your e-paper display permanently unrecoverable damage` 😟

RattyDAVE, 2021-06-15:
Ahhh.. maybe not then!

NeilInnes, 2021-06-15:
For a device that isn't on continuously it may be ok - but I'd prefer it to update slower than get fried 😄

llvllch, 2021-06-15:
This was my issue, on a cycling ticker (more than one coin) the date changes, the token image, the price, and albeit a tiny bit, the sparkline. Throw in the fact that partial refresh often leads to ghosting and needs to fully refreshed every now and again made me think "I'll use the manufacturers code"

E-paper is slow. but on a refresh interval of every 5-10 mins, I barely notice it (unless it's in my line of sight at the time)

llvllch, 2021-06-15:
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

Pretty much, although it doubles sleep time each count. I've committed my first stab at it.

NeilInnes, 2021-06-15:
I've got a prototype of this working - I split the image into 2 parts and updated them sequentially. I've tried both alternative edp2in7 libraries too.

However, partial updates only support black+white - not 4 gray mode. This means the logo and spark line end up ghosting over each other (not so much of an issue if you aren't cycling through different coins of course). 😞

llvllch, 2021-06-16:
e-paper gonna e-paper :)

NeilInnes, 2021-06-16:
lol - think I'll spend a bit more time looking around, but if there if nothing comes up this may need to be closed under "not feasible"

NeilInnes, 2021-07-08:
I'm calling this one - I've tried around 6 different libraries for the display. All have issues with partial updates and even the best ones leaving too much ghosting when cycling coins. The only solution here is a different type of display - but then, it would lose it's charm 🥰

llvllch, 2021-07-08:
A noble effort! My simplistic brain tells me that no one loves Waveshare
screens as much as Waveshare does, so their code is probably aimed at
preserving the hardware.

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

Closed 2021-06-12.

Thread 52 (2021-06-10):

Script / Display freezes after certain time

MPower-max, 2021-06-10:
After following each step from this repository (incl. installation of additional libs from inititial trouble shooting), I was able to get the btcticker running (i used the same hardware, but instead of remote ssh access, I went for a 32 bit Raspian image and installed everything directly on the desktop with the console).

Great work and fantastic features! It is exactly the device I was looking for with only a few minor flaws:

I use the cycling option with 5 different crypto coins. After a certain time (it seems to be reproducable), the display gets stuck. After a restart (unplugging and plugging in the power cable), everything works normal again.

I wrote a small script and added it to crontab on the raspi, so that it starts the btcticker automatically on start up and it also restarts the Rapi slightly before the program usually crashes. This works absolutely fine for me at the moment, but I thought there might be an easier (maybe less stressful for the Raspi) solution for the issue with the program getting stuck?

Moreover, it would be great to have a simple way to shut down the Raspi properly (instead of only unplugging the power USB cable). Do you think it would be possible to include that option in combination with e.g. a button press-and-hold on the e-ink display?

Many thanks (please excuse if I have missed an easy solution as I am quite new to programming)!

Cheers, Max

llvllch, 2021-06-10:
This is excellent to hear! Good to see that you're coding...

I've not been able to get that error. Do you get an error message when it happens? I think that for faster refresh rates, coingecko may stop returning data.

One of the reasons I might not be seeing it is that I used systemd for process control, and I think it may be handling the restarts for me.

The power button is a good idea. I'll have a look at adding something. Let me know if you come up with anything good :)

MPower-max, 2021-06-12:
Sorry for not responding earlier ...

Actually, I tried to reproduce the error in the last few days and it seems that it only occurs under the following conditions:

- script is started automatically via crontab
- no inputs (e.g. via keyboard) while the device is running
- no other errors occur (such as a lost connection to the Wifi or coingecko not available)

Maybe the Raspian has a hidden sleep or hibernate mode when there are absolutely no inputs after start up, because when the display freezes the Raspi status LED blinks very consistent (same time on and off), but I could not find any additional information for my assumption.

I attached also two images from errors I saw recently:
First photo (after freezing) was displayed, as the title indicates, after I left it frozen for some time (if I remember correctly it worked again later on without any tempering).

Second photo was taken later on that evening (I guess it was only because it lost connection somehow).

Cheers, Max

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

llvllch, 2021-06-12:
The first error is an ugly handling of coingecko not returning data and the script trying to draw a graph of no data. I suspect the second is also a coingecko issue.

Bonus: if you pull that little green tab to the left of the screen, the shiny screen protector comes off. It will be much prettier then :)

MPower-max, 2021-06-12:
Many thanks for the prompt explanation and the tip with screen protector 👍 !
As long as I need to solder on the back of the Raspi (with the screen face down on my work bench) I prefer to let it stay in place ;) (I added a small battery (21700) and battery management to run the btcticker for about a day without power supply) and I have not found a proper casing for all the parts.

Cheers

MPower-max, 2021-06-13:
btw ... as I mentioned earlier, I highly appreciate the work you put into the BTC Ticker. Is it possible to donate some coins (ETH, DOGE, BTC Cash, XRP, ... ) to support your work?

Closed 2021-06-12.

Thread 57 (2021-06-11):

Stuck on INFO:root:Getting token Image from Image directory

reddai75, 2021-06-11:
Hello!
that's a great project!
I'm trying to make the project work with a RPI zero W and I followed your instructions. I get stuck to
INFO:root:Getting token Image from Image directory
and after a few minutes my ssh connection drops. I don't think is the power adapter since it powers a RPI4 flawlessy....
could you help me ?
many thanks!

reddai75, 2021-06-11:
Hello! Thanks for the quick answer!
I used Bitcoin... I think I made a mistake somewhere during the installation process. I followed your instructions, first from here https://www.waveshare.com/wiki/2.7inch_e-Paper_HAT
I enabled SPI
then Installed BCM2835 libraries, wiringPi libraries,Install Python libraries, git, I also downloaded the examples.
then as you wrote:
cd e-Paper/RaspberryPi_JetsonNano/python
sudo python3 setup.py install
then I followed the remaining instructions ( I did not install screen, is this the mistake ?)
I'm on a Raspberry PI zero W headless with a 2.7 inch e-paper hat from waveshare.

it hangs too also with the examples :(
thanks again!
Marco

llvllch, 2021-06-11:
Hey Marco. It sounds like you might have missed a step on the waveshare stuff, if their libraries aren't working either.

The hardware you describe is the configuration I use and works without problems. Was it the light version of Rasbian you used? Could it be a missing library?

reddai75, 2021-06-11:
yes I used the light version…
so you have any suggestions?

llvllch, 2021-06-11:
Perhaps try the advice under Troubleshooting on the Readme file ie:

```
sudo apt-get install libopenjp2-7
sudo apt-get install libqt5gui5
sudo apt-get install python-scipy
sudo apt install libatlas-base-dev
```

reddai75, 2021-06-11:
I did it when I installed it 😩

llvllch, 2021-06-11:
I'd be tempted to start again. I used that exact setup to build an image from scratch a few days ago. It could be a hardware problem, but that's less likely than just a simple mistake.

One thing about the Python libraries step on the waveshare wiki: I only install the Python 3 part....

reddai75, 2021-06-11:
ok ! will do it ! thanks

llvllch, 2021-06-11:
OK.... I'll leave this open until you get it working :)

DickWhitmanBTC, 2021-06-11:
Do you happen to have one that works on a larger epaper display?

reddai75, 2021-06-11:
It seems to work now. The problem is probably with the GPIO female not correctly soldered. I connected the display to the raspberry with the cables and it works... BUT, the buttons do not :(

llvllch, 2021-06-12:
Well that's something. If you can't use the buttons, you can always enable cycle mode so that it automatically scrolls through coins. The orientation and inversion can both also be set in the config file. So at present, the only thing you uses is cycling through currencies.

Anyway, glad you made progress! Closing this issue as it is pretty certainly a waveshare thing.

Closed 2021-06-12.

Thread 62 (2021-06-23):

2.7inch e-Paper e-Ink Display HAT (B) For Raspberry Pi, 264×176, "Red / Black / White, SPIÉis that there is the possibility to make it work with 2.7inch e-Paper e-Ink Display HAT (B) For Raspberry Pi, 264×176, Red / Black / White, SPI"

dish67, 2021-06-23:
Hi

Is that there is the possibility to make it work with 2.7inch e-Paper e-Ink Display HAT (B) For Raspberry Pi, 264×176, Red / Black / White, SPI

I change parameter  on btcticker.py

from waveshare_epd import epd2in7
**to**
from waveshare_epd import epd2in7b_V2

and I change that ...

    epd = epd2in7b_V2.EPD()
#epd = epd2in7()
    epd.init()
#epd.Init_4Gray()
#epd.display_4Gray(epd.getbuffer_4Gray(img))
#epd.display(epd.getbuffer(img))

But I did't see any image on my e-paper ...

do you have any suggestion ??

llvllch, 2021-06-23:
Uncomment the line:
#epd.display(epd.getbuffer(img))
?

dish67, 2021-06-23:
Thank .. 
But I have this error !!  TypeError: display() missing 1 required positional argument: 'imagered'   <==

when I Uncomment the line and reexecute  
def display_image(img):
    epd = epd2in7b_V2.EPD()    epd.init()    print("Clear...")#    epd.Init_4Gray()#    epd.display_4Gray(epd.getbuffer_4Gray(img))    epd.display(epd.getbuffer(img))    epd.sleep()    initkeys()    return

python3 btcticker.py ...Clear...DEBUG:root:HorizontalTraceback (most recent call last):  File "btcticker.py", line 360, in fullupdate    display_image(image)  File "btcticker.py", line 319, in display_image    epd.display(epd.getbuffer(img))TypeError: display() missing 1 required positional argument: 'imagered'
During handling of the above exception, another exception occurred:
Traceback (most recent call last):  File "btcticker.py", line 454, in main    lastcoinfetch=fullupdate(config,lastcoinfetch)  File "btcticker.py", line 366, in fullupdate    display_image(image)  File "btcticker.py", line 319, in display_image    epd.display(epd.getbuffer(img))TypeError: display() missing 1 required positional argument: 'imagered'
During handling of the above exception, another exception occurred:
Traceback (most recent call last):  File "btcticker.py", line 473, in <module>    main()  File "btcticker.py", line 463, in main    display_image(image)  File "btcticker.py", line 319, in display_image    epd.display(epd.getbuffer(img))TypeError: display() missing 1 required positional argument: 'imagered'   <==

Michel Thibault

***@***.***

385 de gascogne ,

J4B 8T2 , Boucherville

Quebec , Canada

    Le mercredi 23 juin 2021, 14 h 03 min 49 s HAE, VEEB ***@***.***> a écrit :

Uncomment the line:
#epd.display(epd.getbuffer(img))
?

—
You are receiving this because you authored the thread.
Reply to this email directly, view it on GitHub, or unsubscribe.

llvllch, 2021-06-23:
This is where it looks like it's different 'image red' sounds like you might have a separate image that determines the red part of the image

Closed 2021-07-21.

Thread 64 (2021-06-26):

After 24/36 hrs service stops

reddai75, 2021-06-26:
Hello,
I have updated btcticker to the latest version, but I still experience a crash (not sure if "crash" is the correct word) every now and then.
I am not a programmer but if there is a way I can contribute in finding the issue I would be happy to help...

llvllch, 2021-06-26:
By crash, do you mean freeze, or does an error screen show? I made a small
but significant change this morning, try updating to that (and thank you
for the help!)

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

reddai75, 2021-06-26:
it depends: for example this morning the pi zero was so slow that I couldn't log in: I inserted username , then after I inserted the password the connection timed out... a couple of days ago I was able to log in but the service was probably stopped or frozen: I checked the status (service btcticker status) and it displayed the last update that occured a couple of hours earlier.
I'll update it over the weekend and let you know!
Thank you for this project!

llvllch, 2021-06-26:
Try the new version. Someone kindly pointed out that the main loop was
generating a lot of network traffic. That's fixed now (I think)

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

reddai75, 2021-06-29:
Hello, I have tried the new version since Sunday, and since then two crashes occured ... I have put btcticker as a service at startup, and here is what I have just get this morning after service btcticker status... as you can see last update occured  around midnight... then nothing.
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

llvllch, 2021-06-29:
Check dmesg and /var/log/syslog to see if there are any clues as to what
happened.

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

reddai75, 2021-07-05:
quick update: now it runs for a couple of days without problems, but after that every now and then the pi zero led starts blinking and there is no screen refresh for up to even 10 hours or more. Later in the day everything goes back to normal… that’s weird.

llvllch, 2021-07-06:
That is weird, I've seen the flashes too, but google has nothing about
them. I suspect it could be a power saving mode. I'll leave this open and
keep investigating.

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

Closed 2021-07-21.

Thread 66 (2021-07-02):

Back frame?

docjfnoel, 2021-07-02:
Hello, I love this project!
You wouldn't have the STL file fort the back frame by any chance? 😊
Thanks!

llvllch, 2021-07-21:
Thanks :) I don't, but if I find one I'll add it to the repository.

Closed 2021-07-21.

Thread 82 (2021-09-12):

Buttons not working

Phozer, 2021-09-12:
Hey

I followed the instructions and got my Ticker to work with no problem. Except for the buttons. No matter when I press them they don't have any effect. Is this a common issue?

What could I have done wrong?

Thanks for your help.

reddai75, 2021-09-13:
hello,
I have had  the same problem. After a lot of investigations,
reinstallations etc I concluded that it was a defective display and asked
for a partial refund to the seller.
If you end to a different conclusion please let me know 😉

--
Marco

Il giorno dom 12 set 2021 alle 21:33 Phozer ***@***.***> ha
scritto:

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

reddai75, 2021-10-02:
update: I bought a second display, tested on an old raspberry pi b+ and the buttons do not work so there must be something we are missing....

llvllch, 2021-10-02:
I defer to the expertise of @Kapujino, on this one. They looked at the button code in a fair bit of depth in their vast improvement to the computational overhead of the code.

glabbe0299, 2021-10-03:
Same thing here.
buttons do nothing.

llvllch, 2021-10-03:
And the waveshare button demo works?

glabbe0299, 2021-10-03:
Not sure how to run that demo I'm not a programming expert

Kapujino, 2021-10-04:
Created https://github.com/llvllch/btcticker/pull/84 as a workaround.
You have to pull the repository again to get the latest changes when the PR is merged. (e.g. `cd ~/btcticker` and `git pull`)

@llvllch this workaround causes endless new threads (mentioned in https://github.com/llvllch/btcticker/pull/76#issuecomment-899797910) but the buttons work again.

The "cleaner" solution is to remove the GPIO cleanup from the upstream library.
Edit the file `~/btcticker/waveshare_epd/epdconfig.py` and remove (or comment) the line 87 (`self.GPIO.cleanup()`).
A change of the upstream library was requested here: https://github.com/waveshare/e-Paper/pull/189
Maybe I should create an issue for that.

If this doesn't fix your issue, please do the following and post the output here:

- `sudo systemctl stop btcticker.service` - this stops the probably running service
- `python3 ~/btcticker/btcticker.py --log debug` - this starts the program with verbose logging into your terminal (you can see what is does)

Sorry for the late reply though :)

reddai75, 2021-10-04:
> The "cleaner" solution is to remove the GPIO cleanup from the upstream library. Edit the file `~/btcticker/waveshare_epd/epdconfig.py` and remove (or comment) the line 87 (`self.GPIO.cleanup()`). A change of the upstream library was requested here: [waveshare/e-Paper#189](https://github.com/waveshare/e-Paper/pull/189) Maybe I should create an issue for that.

works great!! thank you!

reddai75, 2021-10-04:
old on... let me investigate... I did a quick check of the buttons, then I left the screen inverted and it seems not updating anymore...

reddai75, 2021-10-04:
@llvllch I think the problem now is that after pressing the buttons the screen doesn't update anymore

Kapujino, 2021-10-04:
I started the current available version again, cycled a few times through the currencies (always waited until the screen refreshed) and my device is still updating every 300 seconds.

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

And please keep in mind that the Raspberry Pi Zero and the e-ink display are pretty slow and need some time to update.

reddai75, 2021-10-04:
I have on raspberry pi zero(s) and pi(s) model b+ 1.2, I'll come back to you with logs in the next days if I'm sure it's a software issue, the problem may be on my old b+  ( I need to see what happens on the zeros).
What I'm experiencing with my old b+ is mixed results when I press the buttons...
anyway, thanks for your help!

Phozer, 2021-10-10:
The update fixed the issue for me. Thanks all contributing.

Closed 2021-10-04.

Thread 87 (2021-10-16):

FileNotFoundError: [Errno 2] No such file or directory

flyingmonkey12, 2021-10-16:
I feel like I followed every step, but I kept getting these errors...

pi@raspberrypi:~/btcticker $ python3 btcticker.py
sudo: /home/pi/.local/bin/tzupdate: command not found
INFO:root:epd2in7 BTC Frame
INFO:root:{'display': {'cycle': True, 'inverted': False, 'orientation': 90, 'tre                    ndingmode': False, 'showvolume': False, 'showrank': False}, 'ticker': {'currency                    ': 'bitcoin,ethereum,cardano', 'exchange': 'default', 'fiatcurrency': 'usd,eur,g                    bp', 'sparklinedays': 1, 'updatefrequency': 300}}
INFO:root:Getting Data
ERROR:root:[Errno 2] No such file or directory
Traceback (most recent call last):
  File "btcticker.py", line 436, in fullupdate
    display_image(image)
  File "btcticker.py", line 332, in display_image
    epd.Init_4Gray()
  File "/home/pi/btcticker/waveshare_epd/epd2in7.py", line 298, in Init_4Gray
    if (epdconfig.module_init() != 0):
  File "/home/pi/btcticker/waveshare_epd/epdconfig.py", line 76, in module_init
    self.SPI.open(0, 0)
FileNotFoundError: [Errno 2] No such file or directory

During handling of the above exception, another exception occurred:

Traceback (most recent call last):
  File "btcticker.py", line 517, in main
    lastcoinfetch=fullupdate(config,lastcoinfetch)
  File "btcticker.py", line 442, in fullupdate
    display_image(image)
  File "btcticker.py", line 332, in display_image
    epd.Init_4Gray()
  File "/home/pi/btcticker/waveshare_epd/epd2in7.py", line 298, in Init_4Gray
    if (epdconfig.module_init() != 0):
  File "/home/pi/btcticker/waveshare_epd/epdconfig.py", line 76, in module_init
    self.SPI.open(0, 0)
FileNotFoundError: [Errno 2] No such file or directory

During handling of the above exception, another exception occurred:

Traceback (most recent call last):
  File "btcticker.py", line 538, in <module>
    main()
  File "btcticker.py", line 524, in main
    display_image(image)
  File "btcticker.py", line 332, in display_image
    epd.Init_4Gray()
  File "/home/pi/btcticker/waveshare_epd/epd2in7.py", line 298, in Init_4Gray
    if (epdconfig.module_init() != 0):
  File "/home/pi/btcticker/waveshare_epd/epdconfig.py", line 76, in module_init
    self.SPI.open(0, 0)
FileNotFoundError: [Errno 2] No such file or directory

flyingmonkey12, 2021-10-17:
oh boi, now I got this...  I even replaced with a new 2.7 display, wiped out my SD card to start all over again...

pi@raspberrypi:~/btcticker $ python3 -u /home/pi/btcticker/btcticker.py
Matplotlib is building the font cache; this may take a moment.
sudo: /home/pi/.local/bin/tzupdate: command not found
INFO:root:epd2in7 BTC Frame
INFO:root:{'display': {'cycle': True, 'inverted': False, 'orientation': 90, 'trendingmode': False, 'showvolume': False, 'showrank': False, '24h': True}, 'ticker': {'currency': 'bitcoin,ethereum,cardano', 'exchange': 'default', 'fiatcurrency': 'usd,eur,gbp', 'sparklinedays': 1, 'updatefrequency': 300}}
INFO:root:Getting Data
ERROR:root:[Errno 2] No such file or directory
Traceback (most recent call last):
  File "/home/pi/btcticker/btcticker.py", line 440, in fullupdate
    display_image(image)
  File "/home/pi/btcticker/btcticker.py", line 336, in display_image
    epd.Init_4Gray()
  File "/home/pi/btcticker/waveshare_epd/epd2in7.py", line 298, in Init_4Gray
    if (epdconfig.module_init() != 0):
  File "/home/pi/btcticker/waveshare_epd/epdconfig.py", line 76, in module_init
    self.SPI.open(0, 0)
FileNotFoundError: [Errno 2] No such file or directory

During handling of the above exception, another exception occurred:

Traceback (most recent call last):
  File "/home/pi/btcticker/btcticker.py", line 521, in main
    lastcoinfetch=fullupdate(config,lastcoinfetch)
  File "/home/pi/btcticker/btcticker.py", line 446, in fullupdate
    display_image(image)
  File "/home/pi/btcticker/btcticker.py", line 336, in display_image
    epd.Init_4Gray()
  File "/home/pi/btcticker/waveshare_epd/epd2in7.py", line 298, in Init_4Gray
    if (epdconfig.module_init() != 0):
  File "/home/pi/btcticker/waveshare_epd/epdconfig.py", line 76, in module_init
    self.SPI.open(0, 0)
FileNotFoundError: [Errno 2] No such file or directory

During handling of the above exception, another exception occurred:

Traceback (most recent call last):
  File "/home/pi/btcticker/btcticker.py", line 542, in <module>
    main()
  File "/home/pi/btcticker/btcticker.py", line 528, in main
    display_image(image)
  File "/home/pi/btcticker/btcticker.py", line 336, in display_image
    epd.Init_4Gray()
  File "/home/pi/btcticker/waveshare_epd/epd2in7.py", line 298, in Init_4Gray
    if (epdconfig.module_init() != 0):
  File "/home/pi/btcticker/waveshare_epd/epdconfig.py", line 76, in module_init
    self.SPI.open(0, 0)
FileNotFoundError: [Errno 2] No such file or directory

hallard, 2021-12-16:
don't want to create another issue but in my case was missing spidev solved by:

`pip3 install spidev`

Worth adding it in [requirements.txt](https://github.com/veebch/btcticker/blob/main/requirements.txt)

hallard, 2021-12-16:
Was a quite old one lite version on my side, not tested on latest lite but won't hurt for sure :-)

Closed 2021-12-16.

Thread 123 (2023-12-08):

Service running, no display

JBP3D, 2023-12-08:
Followed the steps, everything is running and had no errors but the display does not show anything

veebch, 2023-12-08:
There are some waveshare test codes in their repository. Can you display to the screen when you run them?

JBP3D, 2023-12-08:
> There are some waveshare test codes in their repository. Can you display to the screen when you run them?
>
> EDIT: You might have V2 of the screen, if so see line 40 of the code. You need to comment out a line and then uncomment the one above

Thank you for the quick reply! My screen indeed has a sticker V2 on it so I'll try that and will update.

JBP3D, 2023-12-08:
> There are some waveshare test codes in their repository. Can you display to the screen when you run them?
>
> EDIT: You might have V2 of the screen, if so see line 40 of the code. You need to comment out a line and then uncomment the one above

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

I did this but it's still not showing. Did I do it right?

veebch, 2023-12-08:
That looks good. What does output does the code give to the terminal when you run it?

JBP3D, 2023-12-10:
Hey sorry for the late response, had a few busy days.

I'm not sure what you mean with the output? I just used the commands to start the service and rebooted. using status shows btcticker is active running

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

veebch, 2023-12-14:
You can stop that service and then try running it interactively from the command line.

The first thing I would do is try to get some waveshare test code running on it. That will help you narrow down the problem...

E-IG88, 2024-02-05:
I'm having the same issue. Was this ever resolved and if so, how? I'm running a Raspberry Pi 4B with a V2 screen.

E-IG88, 2024-02-05:
@veebch When you reference main.py, I'm assuming your talking about btcticker.py. I have already uncommented line 40 and commented out the one above it as shown below. I also searched the rest of the btcticker.py file for anything with the keyword "v2" and the only other section that has something starts at line 431 but I'm not sure what to do, if anything.

line 39: #from waveshare_epd import epd2in7
line 40: from waveshare_epd import epd2in7_V2 as epd2in7

def display_image(img):
    epd = epd2in7.EPD()
    # Also change to V2 if using a V2 screen
    epd.Init_4Gray()
    epd.display_4Gray(epd.getbuffer_4Gray(img))
    epd.sleep()
    thekeys = initkeys()
#   Have to remove and add key events to make them work again
    removekeyevent(thekeys)
    addkeyevent(thekeys)
    logging.info("Sent image to screen")
    return

veebch, 2024-02-05:
You're right.... btcticker.py

You shouldn't need to change the 431 bit. Can you get the waveshare demos to work?

E-IG88, 2024-02-05:
I've downloaded demos from Waveshare and can successfully display a "Hello World" demo to the screen so I know the e-ink display is working properly.

veebch, 2024-02-06:
Then it looks like gpiozero is doing it.

E-IG88, 2024-02-06:
@veebch This was it. I was running the script at the same time, or not closing Geany before running the code in the terminal. lgpio reserves that pin and won't let another process use it until it's been closed. I'm getting a lot closer now but still no display on the screen although it looks like it's trying to write to the screen. This is my output in terminal when running python3 btcticker.py --log DEBUG

username@raspberrypi2:~/btcticker $ python3 btcticker.py --log DEBUG
Traceback (most recent call last):
  File "/home/username/.local/bin/tzupdate", line 5, in <module>
    from tzupdate import main
ModuleNotFoundError: No module named 'tzupdate'
INFO:root:epd2in7 BTC Frame
INFO:root:{'display': {'cycle': True, 'inverted': False, 'orientation': 180, 'trendingmode': False}, 'ticker': {'currency': 'bitcoin,ripple,ethereum', 'exchange': 'default', 'fiatcurrency': 'gbp,usd,btc', 'sparklinedays': 7, 'updatefrequency': 300}}
DEBUG:root:Setup GPIO keys
DEBUG:root:Add key events
INFO:root:Getting Data
DEBUG:root:[https://api.coingecko.com/api/v3/coins/bitcoin/market_chart/range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](https://gcc02.safelinks.protection.outlook.com/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)
DEBUG:urllib3.connectionpool:Starting new HTTPS connection (1): [api.coingecko.com:443](https://gcc02.safelinks.protection.outlook.com/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)
DEBUG:urllib3.connectionpool:[https://api.coingecko.com:443](https://gcc02.safelinks.protection.outlook.com/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) "GET /api/v3/coins/bitcoin/market_chart/range?vs_currency=gbp&from=1706620854&to=1707225654 HTTP/1.1" 429 187
DEBUG:root:Got price for the last 7 days from CoinGecko
DEBUG:waveshare_epd.epd2in7_V2:e-Paper busy
DEBUG:waveshare_epd.epd2in7_V2:e-Paper busy release
DEBUG:waveshare_epd.epd2in7_V2:e-Paper busy
DEBUG:waveshare_epd.epd2in7_V2:e-Paper busy release
DEBUG:waveshare_epd.epd2in7_V2:Horizontal
ERROR:root:list index out of range
DEBUG:waveshare_epd.epd2in7_V2:e-Paper busy
DEBUG:waveshare_epd.epd2in7_V2:e-Paper busy release
DEBUG:waveshare_epd.epd2in7_V2:e-Paper busy
DEBUG:waveshare_epd.epd2in7_V2:e-Paper busy release
DEBUG:waveshare_epd.epd2in7_V2:Horizontal
Traceback (most recent call last):
  File "/home/username/btcticker/btcticker.py", line 545, in fullupdate
    pricestack, ATH = getData(config, other)
                      ^^^^^^^^^^^^^^^^^^^^^^
  File "/home/username/btcticker/btcticker.py", line 160, in getData
    timeseriesarray = rawtimeseries['prices']
                      ~~~~~~~~~~~~~^^^^^^^^^^
KeyError: 'prices'

During handling of the above exception, another exception occurred:

Traceback (most recent call last):
  File "/home/username/btcticker/btcticker.py", line 641, in main
    lastcoinfetch = fullupdate(config, lastcoinfetch)
                    ^^^^^^^^^^^^^^^^^^^^^^^^^^^^^^^^^
  File "/home/username/btcticker/btcticker.py", line 557, in fullupdate
    display_image(image)
  File "/home/username/btcticker/btcticker.py", line 435, in display_image
    epd.display_4Gray(epd.getbuffer_4Gray(img))
  File "/home/username/btcticker/waveshare_epd/epd2in7_V2.py", line 450, in display_4Gray
    temp1 = image[i*2+j]
            ~~~~~^^^^^^^
IndexError: list index out of range

During handling of the above exception, another exception occurred:

Traceback (most recent call last):
  File "/home/username/btcticker/btcticker.py", line 663, in <module>
    main()
  File "/home/username/btcticker/btcticker.py", line 652, in main
    display_image(image)
  File "/home/username/btcticker/btcticker.py", line 435, in display_image
    epd.display_4Gray(epd.getbuffer_4Gray(img))
  File "/home/username/btcticker/waveshare_epd/epd2in7_V2.py", line 450, in display_4Gray
    temp1 = image[i*2+j]
            ~~~~~^^^^^^^
IndexError: list index out of range

E-IG88, 2024-02-06:
Great, thanks! I will try it again later. Just out of curiosity, is it normal for all the other errors to occur if coingecko API refuses the connection, in particular "IndexError: list index out of range" ?

veebch, 2024-02-06:
Since the code was written, coingecko seem to be a lot more frequently throttling connections. That said, the code should spot the error code and stop gracefully, rather than try to run without data. I'll make that tweak next chance I get.

veebch, 2024-02-06:
The cup of tea rule has served me well in the past. I imagine you're hitting the url via your computer, which hasn't been throttled. If you get no error when accessing it via curl from the pi, that might be an issue

E-IG88, 2024-02-06:
Looks like your right. I have to time it almost perfectly but I finally got Coingecko to return an HTTP 200 OK. Still no display but I'm really close. Based from what I see near the bottom of the this traceback, it's still complaining about something related to the V2 screen. Does any of this make sense to you? Really appreciate all the help you've provided!
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

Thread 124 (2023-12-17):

Fresh OS, can't get it running...

ZOMGVTEK, 2023-12-17:
Why hello there.

On a fresh install, I cant manage to get this running. Pi3, 64bit lite (bullseye). Here is the output...

The waveshare demo runs fine on this one, I have this ticker running on a very old Raspbian install, but its unreliable and crashes frequently.

Traceback (most recent call last):
  File "/home/admin/.local/bin/tzupdate", line 5, in <module>
    from tzupdate import main
ModuleNotFoundError: No module named 'tzupdate'
INFO:root:epd2in7 BTC Frame
INFO:root:{'display': {'cycle': True, 'cyclefiat': True, 'inverted': False, 'orientation': 90, 'trendingmode': False, 'showvolume': False, 'showrank': False, '24h': True, 'locale': 'en_US'}, 'ticker': {'currency': 'bitcoin,ethereum,cardano', 'exchange': 'default', 'fiatcurrency': 'usd,btc,gbp', 'sparklinedays': 1, 'updatefrequency': 300}}
INFO:root:Getting Data
ERROR:root:'FreeTypeFont' object has no attribute 'getsize'
Traceback (most recent call last):
  File "/home/admin/btcticker/./btcticker.py", line 548, in fullupdate
    image = updateDisplay(config, pricestack, other)
  File "/home/admin/btcticker/./btcticker.py", line 318, in updateDisplay
    tokenimage.thumbnail(resize, Image.ANTIALIAS)
AttributeError: module 'PIL.Image' has no attribute 'ANTIALIAS'

During handling of the above exception, another exception occurred:

Traceback (most recent call last):
  File "/home/admin/btcticker/./btcticker.py", line 640, in main
    lastcoinfetch = fullupdate(config, lastcoinfetch)
  File "/home/admin/btcticker/./btcticker.py", line 554, in fullupdate
    image = beanaproblem(
  File "/home/admin/btcticker/./btcticker.py", line 247, in beanaproblem
    writewrappedlines(image, "Issue: "+message)
  File "/home/admin/btcticker/./btcticker.py", line 113, in writewrappedlines
    _place_text(img, line, 0, y_text, fontsize, fontstring)
  File "/home/admin/btcticker/./btcticker.py", line 102, in _place_text
    text_width, _ = font.getsize(text)
AttributeError: 'FreeTypeFont' object has no attribute 'getsize'

During handling of the above exception, another exception occurred:

Traceback (most recent call last):
  File "/home/admin/btcticker/./btcticker.py", line 662, in <module>
    main()
  File "/home/admin/btcticker/./btcticker.py", line 650, in main
    image = beanaproblem(str(e)+" Line: "+str(e.__traceback__.tb_lineno))
  File "/home/admin/btcticker/./btcticker.py", line 247, in beanaproblem
    writewrappedlines(image, "Issue: "+message)
  File "/home/admin/btcticker/./btcticker.py", line 113, in writewrappedlines
    _place_text(img, line, 0, y_text, fontsize, fontstring)
  File "/home/admin/btcticker/./btcticker.py", line 102, in _place_text
    text_width, _ = font.getsize(text)
AttributeError: 'FreeTypeFont' object has no attribute 'getsize'

TheWalrus057, 2023-12-18:
I have been experiencing the exact same same issue, have tried a few times to install but receive this series of errors. Researching it seems that Pillow has issues w the getsize function w the launch of 10.0.0, installing PIL 9.5.0 (pip install Pillow==9.5.0) got me through this error but it would crash upon cycling tokens citing "the LED is closed or uninitialized". With the autostart service created/enabled it runs again upon crashing but continues to show the first token set in config.yaml

Here is the traceback I get after installing PIL 9.5.0:
ERROR:root:LED is closed or uninitialized
Traceback (most recent call last):
  File "/usr/lib/python3/dist-packages/gpiozero/output_devices.py", line 96, in _write
    self.pin.state = self._value_to_state(value)
AttributeError: 'NoneType' object has no attribute 'state'

During handling of the above exception, another exception occurred:

Traceback (most recent call last):
  File "/usr/lib/python3/dist-packages/gpiozero/devices.py", line 580, in _check_open
    super(GPIODevice, self)._check_open()
  File "/usr/lib/python3/dist-packages/gpiozero/devices.py", line 215, in _check_open
    raise DeviceClosed(
gpiozero.exc.DeviceClosed: LED is closed or uninitialized

During handling of the above exception, another exception occurred:

Traceback (most recent call last):
  File "/home/pi/btcticker/btcticker.py", line 549, in fullupdate
    display_image(image)
  File "/home/pi/btcticker/btcticker.py", line 433, in display_image
    epd.Init_4Gray()
  File "/home/pi/btcticker/waveshare_epd/epd2in7.py", line 298, in Init_4Gray
    if (epdconfig.module_init() != 0):
  File "/home/pi/btcticker/waveshare_epd/epdconfig.py", line 102, in module_init
    self.GPIO_PWR_PIN.on()
  File "/usr/lib/python3/dist-packages/gpiozero/output_devices.py", line 219, in on
    self._write(True)
  File "/usr/lib/python3/dist-packages/gpiozero/output_devices.py", line 98, in _write
    self._check_open()
  File "/usr/lib/python3/dist-packages/gpiozero/devices.py", line 583, in _check_open
    raise GPIODeviceClosed(str(e))
gpiozero.exc.GPIODeviceClosed: LED is closed or uninitialized

During handling of the above exception, another exception occurred:

Traceback (most recent call last):
  File "/usr/lib/python3/dist-packages/gpiozero/output_devices.py", line 96, in _write
    self.pin.state = self._value_to_state(value)
AttributeError: 'NoneType' object has no attribute 'state'

During handling of the above exception, another exception occurred:

Traceback (most recent call last):
  File "/usr/lib/python3/dist-packages/gpiozero/devices.py", line 580, in _check_open
    super(GPIODevice, self)._check_open()
  File "/usr/lib/python3/dist-packages/gpiozero/devices.py", line 215, in _check_open
    raise DeviceClosed(
gpiozero.exc.DeviceClosed: LED is closed or uninitialized

During handling of the above exception, another exception occurred:

Traceback (most recent call last):
  File "/home/pi/btcticker/btcticker.py", line 640, in main
    lastcoinfetch = fullupdate(config, lastcoinfetch)
  File "/home/pi/btcticker/btcticker.py", line 556, in fullupdate
    display_image(image)
  File "/home/pi/btcticker/btcticker.py", line 433, in display_image
    epd.Init_4Gray()
  File "/home/pi/btcticker/waveshare_epd/epd2in7.py", line 298, in Init_4Gray
    if (epdconfig.module_init() != 0):
  File "/home/pi/btcticker/waveshare_epd/epdconfig.py", line 102, in module_init
    self.GPIO_PWR_PIN.on()
  File "/usr/lib/python3/dist-packages/gpiozero/output_devices.py", line 219, in on
    self._write(True)
  File "/usr/lib/python3/dist-packages/gpiozero/output_devices.py", line 98, in _write
    self._check_open()
  File "/usr/lib/python3/dist-packages/gpiozero/devices.py", line 583, in _check_open
    raise GPIODeviceClosed(str(e))
gpiozero.exc.GPIODeviceClosed: LED is closed or uninitialized

During handling of the above exception, another exception occurred:

Traceback (most recent call last):
  File "/usr/lib/python3/dist-packages/gpiozero/output_devices.py", line 96, in _write
    self.pin.state = self._value_to_state(value)
AttributeError: 'NoneType' object has no attribute 'state'

During handling of the above exception, another exception occurred:

Traceback (most recent call last):
  File "/usr/lib/python3/dist-packages/gpiozero/devices.py", line 580, in _check_open
    super(GPIODevice, self)._check_open()
  File "/usr/lib/python3/dist-packages/gpiozero/devices.py", line 215, in _check_open
    raise DeviceClosed(
gpiozero.exc.DeviceClosed: LED is closed or uninitialized

During handling of the above exception, another exception occurred:

Traceback (most recent call last):
  File "/home/pi/btcticker/btcticker.py", line 662, in <module>
    main()
  File "/home/pi/btcticker/btcticker.py", line 651, in main
    display_image(image)
  File "/home/pi/btcticker/btcticker.py", line 433, in display_image
    epd.Init_4Gray()
  File "/home/pi/btcticker/waveshare_epd/epd2in7.py", line 298, in Init_4Gray
    if (epdconfig.module_init() != 0):
  File "/home/pi/btcticker/waveshare_epd/epdconfig.py", line 102, in module_init
    self.GPIO_PWR_PIN.on()
  File "/usr/lib/python3/dist-packages/gpiozero/output_devices.py", line 219, in on
    self._write(True)
  File "/usr/lib/python3/dist-packages/gpiozero/output_devices.py", line 98, in _write
    self._check_open()
  File "/usr/lib/python3/dist-packages/gpiozero/devices.py", line 583, in _check_open
    raise GPIODeviceClosed(str(e))
gpiozero.exc.GPIODeviceClosed: LED is closed or uninitialized

I love this project and appreciate everything you do veebch <3

veebch, 2023-12-19:
It looks like a combination of things. I think regressing Pil to 9.2 might do the trick, but it's better to change the code so that we can use the newest version.

I'll have a tinker with it later on and see if I can fix it.

Closed 2023-12-19.

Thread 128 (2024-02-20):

Perhaps there are new package names/schemas

ScottTheHippy, 2024-02-20:
Howdy,

I've attempted this with a clean install (username 'pi") and start having snags with the loading of dependencies.  Specifically here:

sudo apt-get update
sudo apt-get install -y python3-pip mc git libopenjp2-7
sudo apt-get install -y libatlas-base-dev python3-pil python-numpy python-matplotlib

The update is fine but all of these dependancies are failing.   Here are the messages:

Package python-matplotlib is not available, but is referred to by another package.
This may mean that the package is missing, has been obsoleted, or
is only available from another source

Package python-numpy is not available, but is referred to by another package.
This may mean that the package is missing, has been obsoleted, or
is only available from another source

E: Package 'python-numpy' has no installation candidate
E: Package 'python-matplotlib' has no installation candidate

Any ideas?  Thanks!

veebch, 2024-02-20:
maybe python3-numpy and python3-matplotlib?

ScottTheHippy, 2024-02-20:
I’m out of my depth on this, but I did see there was a ‘pip install numpy’ approach, but it didn’t get me any closer to working.  :(. If you want to have me try anything, I’ll gladly start with a fresh image and give more detailed feedback on the errors that come up.  Cheers!

veebch, 2024-02-20:
I'll leave this open until one of us figures this out :)

ScottTheHippy, 2024-02-21:
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

Are these warnings indicative of failed installations?

ScottTheHippy, 2024-02-21:
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
As a theory test, I tried just to pip install pandas after the prior error and it looks as though the installation succeeded.   I didn't mention prior, but in case it matters, this is a clean reimage on a RPi v3.

ScottTheHippy, 2024-02-21:
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
Then attempting to launch edify.py, this is the error (the same that I've been getting since I started).
Cheers!

veebch, 2024-02-21:
edify.py?

ScottTheHippy, 2024-02-21:
Off the top- sorry for the confusion between btctracker and edify- I've been trying both and didn't figure that I'd make two issues over them seeming to have the same issue.  There was a clue in your reply.  I was using the "Raspberry Pi OS (Legacy 32-bit)" image instead of the "Raspberry Pi OS (Legacy 32-bit) Lite", which has Python and PIP (and Git) installed by default.  I just reimaged with Lite, installed PIP and Git, and followed the instructions posted on your edifier page and got similar errors (attached).  I'm about to do it again and follow the btctracker instructions and will post back when that's done.
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

The first error message is during the install of the items listed in the requirements.txt.  Looks like it might be bumpy-specific.
![Uploading Screen Shot 2024-02-21 at 1.37.15 PM.png…]()

The second error message is what happened after I tried to execute the (edify.py) script.

Thanks and more to come!

ScottTheHippy, 2024-02-22:
I was trying to figure out why my Waveshare demos print to the screen but btcticker doesn't and saw your comment in code about remarking one line and unremarking another if using "V2" of the display (which I am, based on the demos that work).  I followed your guidance and now get different error messages, and still no display.  Error attached.  Does that help anything?
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

ScottTheHippy, 2024-02-22:
Howdy Veebch,  I found your other thread about this V2 Waveshare business (https://github.com/veebch/btcticker/issues/123) and am happy to report I'm in business.  It threw me for a moment as I was editing the epd2in7_V2.py in the e-Paper\RaspberryPi_JetsonNano\python\lib\waveshare_epd directory and not seeing any headway.  I'd forgotten that your setup script copies those files to a waveshare directory with btcticker.  D'oh!  In any case, changing those lines was the last hurdle.  I don't know if you want to notate this  in addition to the other details (the Lite OS version, the "3" in the python install syntax) in the setup instructions or what, but YAY!  Thanks for your help!

Closed 2024-02-22.

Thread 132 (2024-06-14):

Waveshare V2 not working (NameError)

iddqd23, 2024-06-14:
If I comment out line 39 and uncomment line 41 in btcticker.py the screen stays white. If I additional change line 483 in btcticker.py to "epd = epd2in7_V2.EPD()" or "epd = epd2in7V2.EPD()" I get the error "NameError: name 'epd2in7_V2' is not defined". Any help?

veebch, 2024-06-14:
The second change (to line 438) is creating an error. Only the change of line 39 and 41 is needed. I'm not sure why the screen stays white, does it display the waveshare examples?

iddqd23, 2024-06-14:
No, the display stays white without any examples. Perhaps I have the wrong screen [DEBO EPA 2.7 Entwicklerboards](urlhttps://www.reichelt.de/entwicklerboards-display-epaper-2-7-schwarz-weiss-debo-epa-2-7-p224220.html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).

When I start the btcticker.py via ssh, it displays the following message:

`sudo: /home/pi/.local/bin/tzupdate: command not found
INFO:root:epd2in7 BTC Frame
INFO:root:{'display': {'24h': True, 'cycle': True, 'cyclefiat': True, 'inverted': False, 'locale': 'en_US', 'orientation': 270, 'showrank': False, 'showvolume': False, 'trendingmode': False}, 'ticker': {'currency': 'ethereum,cardano,bitcoin', 'exchange': 'default', 'fiatcurrency': 'usd,btc,gbp', 'sparklinedays': 1, 'updatefrequency': 300}}
INFO:root:Getting Data`

veebch, 2024-06-14:
That looks like the right board. The demo code on https://github.com/waveshareteam/e-Paper/tree/master/RaspberryPi_JetsonNano/python/examples should work on it.

The output you posted is not saying anything about the code successfully getting the data, so it's possible coingecko isn't returning data

iddqd23, 2024-06-14:
The demo also don't work. I'm starting to get the feeling that my Pi Zero is broken. Although I can hardly imagine that, since access is possible via ssh.

veebch, 2024-06-14:
have you tried disconnecting the ePaper from the pi and then reattaching it? It *may* be that the screen isn't seated on the pins correctly

iddqd23, 2024-06-18:
I have now tried it with a new Raspberry Pi Zero and everything is working again. So it was actually my Pi that was broken. Many thanks for your help.

Closed 2024-06-18.

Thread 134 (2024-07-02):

Failed to add edge detection

will0913, 2024-07-02:
After finally installed some of the missing modules, the latest issue seems to be with the display itself.
I have a waveshare 2.9 inch V2, and I've changed some of the values in the btcticker.py.
But I'm getting the following error message. How do I go about fixing it?

`sudo: /home/pi/.local/bin/tzupdate: command not found
INFO:root:epd2in9_V2 BTC Frame
INFO:root:{'display': {'cycle': True, 'cyclefiat': True, 'inverted': False, 'orientation': 90, 'trendingmode': False, 'showvolume': False, 'showrank': False, '24h': True, 'locale': 'en_US'}, 'ticker': {'currency': 'bitcoin,ethereum,cardano', 'exchange': 'default', 'fiatcurrency': 'usd,btc,gbp', 'sparklinedays': 1, 'updatefrequency': 300}}
ERROR:root:Failed to add edge detection
Traceback (most recent call last):
  File "/home/pi/btcticker/btcticker.py", line 660, in main
    addkeyevent(thekeys)
  File "/home/pi/btcticker/btcticker.py", line 515, in addkeyevent
    GPIO.add_event_detect(thekeys[0], GPIO.FALLING, callback=keypress, bouncetime=btime)
RuntimeError: Failed to add edge detection

During handling of the above exception, another exception occurred:

Traceback (most recent call last):
  File "/home/pi/btcticker/btcticker.py", line 716, in <module>
    main()
  File "/home/pi/btcticker/btcticker.py", line 705, in main
    display_image(image)
  File "/home/pi/btcticker/btcticker.py", line 491, in display_image
    addkeyevent(thekeys)
  File "/home/pi/btcticker/btcticker.py", line 515, in addkeyevent
    GPIO.add_event_detect(thekeys[0], GPIO.FALLING, callback=keypress, bouncetime=btime)
RuntimeError: Failed to add edge detection`

veebch, 2024-07-02:
Does the 2.9 inch screen have buttons? If not then you might have to remove those parts of the code.

will0913, 2024-07-04:
Okay. I think I'm in over my head. I'll go through the code and see if I can figure it out. Thanks so much for the assistance.

Closed 2024-07-04.

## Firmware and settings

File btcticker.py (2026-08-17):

#!/usr/bin/python3

"""
  main.py - a script for a cryptocurrency ticker.
    
     Copyright (C) 2023 Veeb Projects https://veeb.ch

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
"""


from babel.numbers import decimal, format_currency, format_scientific
from babel import Locale
import argparse
import textwrap
import socket
import yaml
import matplotlib.pyplot as plt
from PIL import Image, ImageOps
from PIL import ImageFont
from PIL import ImageDraw
import currency
import os
import sys
import logging
import RPi.GPIO as GPIO
from waveshare_epd import epd2in7

# from waveshare_epd import epd2in7_V2 as epd2in7 #(comment out line above and uncomment this line if you're using v2). 
# Also check https://github.com/waveshareteam/e-Paper/issues/322 to see whether waveshare have fixed the V2 bug
import time
import requests
import urllib
import json
import matplotlib as mpl

mpl.use("Agg")

dirname = os.path.dirname(__file__)
picdir = os.path.join(os.path.dirname(os.path.realpath(__file__)), "images")
fontdir = os.path.join(os.path.dirname(os.path.realpath(__file__)), "fonts/googlefonts")
configfile = os.path.join(os.path.dirname(os.path.realpath(__file__)), "config.yaml")
font_date = ImageFont.truetype(os.path.join(fontdir, "PixelSplitter-Bold.ttf"), 11)
headers = {
    "User-Agent": "Mozilla/5.0 (Macintosh; Intel Mac OS X 10_10_1) AppleWebKit/537.36 (KHTML, like Gecko) Chrome/39.0.2171.95 Safari/537.36"
}
button_pressed = 0


def internet(hostname="google.com"):
    """
    Host: google.com
    """
    try:
        # see if we can resolve the host name -- tells us if there is
        # a DNS listening
        host = socket.gethostbyname(hostname)
        # connect to the host -- tells us if the host is actually
        # reachable
        s = socket.create_connection((host, 80), 2)
        s.close()
        return True
    except:
        logging.info("Google says No")
        time.sleep(1)
    return False


def human_format(num):
    num = float("{:.3g}".format(num))
    magnitude = 0
    while abs(num) >= 1000:
        magnitude += 1
        num /= 1000.0
    return "{}{}".format(
        "{:f}".format(num).rstrip("0").rstrip("."), ["", "K", "M", "B", "T"][magnitude]
    )


def _place_text(
    img, text, x_offset=0, y_offset=0, fontsize=40, fontstring="Forum-Regular", fill=0
):
    """
    Put some centered text at a location on the image.
    """
    draw = ImageDraw.Draw(img)
    try:
        filename = os.path.join(dirname, "./fonts/googlefonts/" + fontstring + ".ttf")
        font = ImageFont.truetype(filename, fontsize)
    except OSError:
        font = ImageFont.truetype("/usr/share/fonts/TTF/DejaVuSans.ttf", fontsize)
    img_width, img_height = img.size
    try:
      text_width = font.getbbox(text)[2]
      text_height = font.getbbox(text)[3]
    except:
      text_width = font.getsize(text)[0]
      text_height = font.getsize(text)[1]
    draw_x = (img_width - text_width) // 2 + x_offset
    draw_y = (img_height - text_height) // 2 + y_offset
    draw.text((draw_x, draw_y), text, font=font, fill=fill)


def writewrappedlines(
    img, text, fontsize=16, y_text=20, height=15, width=25, fontstring="Roboto-Light"
):
    lines = textwrap.wrap(text, width)
    numoflines = 0
    for line in lines:
        _place_text(img, line, 0, y_text, fontsize, fontstring)
        y_text += height
        numoflines += 1
    return img


def getgecko(url):
    try:
        geckojson = requests.get(url, headers=headers).json()
        connectfail = False
    except requests.exceptions.RequestException as e:
        logging.error("Issue with CoinGecko")
        connectfail = True
        geckojson = {}
    return geckojson, connectfail


def getData(config, other):
    """
    The function to grab the data (TO DO: need to test properly)
    """

    sleep_time = 10
    num_retries = 5
    whichcoin, fiat = configtocoinandfiat(config)
    logging.info("Getting Data")
    days_ago = int(config["ticker"]["sparklinedays"])
    endtime = int(time.time())
    starttime = endtime - 60 * 60 * 24 * days_ago
    starttimeseconds = starttime
    endtimeseconds = endtime
    fiathistory = fiat
    if fiat == "usdt":
        fiathistory = "usd"
    geckourlhistorical = (
        "https://api.coingecko.com/api/v3/coins/"
        + whichcoin
        + "/market_chart/range?vs_currency="
        + fiathistory
        + "&from="
        + str(starttimeseconds)
        + "&to="
        + str(endtimeseconds)
    )
    logging.debug(geckourlhistorical)
    timeseriesstack = []
    for x in range(0, num_retries):
        rawtimeseries, connectfail = getgecko(geckourlhistorical)
        if connectfail == True:
            pass
        else:
            logging.debug(
                "Got price for the last " + str(days_ago) + " days from CoinGecko"
            )
            timeseriesarray = rawtimeseries["prices"]
            length = len(timeseriesarray)
            i = 0
            while i < length:
                timeseriesstack.append(float(timeseriesarray[i][1]))
                i += 1
            # A little pause before hiting the api again
            time.sleep(1)
            # Get the price
        if config["ticker"]["exchange"] == "default":
            geckourl = (
                "https://api.coingecko.com/api/v3/coins/markets?vs_currency="
                + fiat
                + "&ids="
                + whichcoin
            )
            logging.debug(geckourl)
            rawlivecoin, connectfail = getgecko(geckourl)
            if connectfail == True:
                pass
            else:
                logging.debug(rawlivecoin[0])
                liveprice = rawlivecoin[0]
                pricenow = float(liveprice["current_price"])
                alltimehigh = float(liveprice["ath"])
                # Quick workaround for error being thrown for obscure coins. TO DO: Examine further
                try:
                    other["market_cap_rank"] = int(liveprice["market_cap_rank"])
                except:
                    config["display"]["showrank"] = False
                    other["market_cap_rank"] = 0
                other["volume"] = float(liveprice["total_volume"])
                timeseriesstack.append(pricenow)
                if pricenow > alltimehigh:
                    other["ATH"] = True
                else:
                    other["ATH"] = False
        else:
            geckourl = (
                "https://api.coingecko.com/api/v3/exchanges/"
                + config["ticker"]["exchange"]
                + "/tickers?coin_ids="
                + whichcoin
                + "&include_exchange_logo=false"
            )
            logging.debug(geckourl)
            rawlivecoin, connectfail = getgecko(geckourl)
            if connectfail == True:
                pass
            else:
                theindex = -1
                upperfiat = fiat.upper()
                for i in range(len(rawlivecoin["tickers"])):
                    target = rawlivecoin["tickers"][i]["target"]
                    if target == upperfiat:
                        theindex = i
                        logging.debug("Found " + upperfiat + " at index " + str(i))
                #       if UPPERFIAT is not listed as a target theindex==-1 and it is time to go to sleep
                if theindex == -1:
                    logging.error(
                        "The exchange is not listing in "
                        + upperfiat
                        + ". Misconfigured - shutting down script"
                    )
                    sys.exit()
                liveprice = rawlivecoin["tickers"][theindex]
                pricenow = float(liveprice["last"])
                # For non-default the Rank does not show in the API, so leave blank
                other["market_cap_rank"] = 0
                other["volume"] = float(liveprice["converted_volume"]["usd"])
                # For non-default the ATH does not show in the API, so show it when price reaches *pinky in mouth* ONE MILLION DOLLARS
                alltimehigh = 1000000.0
                logging.debug("Got Live Data From CoinGecko")
                timeseriesstack.append(pricenow)
                if pricenow > alltimehigh:
                    other["ATH"] = True
                else:
                    other["ATH"] = False
        if connectfail == True:
            message = "Trying again in ", sleep_time, " seconds"
            logging.warn(message)
            # wait before trying to fetch the data again
            time.sleep(sleep_time)
            sleep_time *= 2  # exponential backoff
        else:
            break
    return timeseriesstack, other


def beanaproblem(message):
    #   A visual cue that the wheels have fallen off
    thebean = Image.open(os.path.join(picdir, "thebean.bmp"))
    # 255: clear the image with white
    image = Image.new("L", (264, 176), 255)
    draw = ImageDraw.Draw(image)
    image.paste(thebean, (60, 45))
    draw.text(
        (95, 15), str(time.strftime("%-H:%M %p, %-d %b %Y")), font=font_date, fill=0
    )
    writewrappedlines(image, "Issue: " + message)
    return image


def makeSpark(pricestack):
    # Draw and save the sparkline that represents historical data
    # Subtract the mean from the sparkline to make the mean appear on the plot (it's really the x axis)
    themean = sum(pricestack) / float(len(pricestack))
    x = [xx - themean for xx in pricestack]
    fig, ax = plt.subplots(1, 1, figsize=(10, 3))
    plt.plot(x, color="k", linewidth=6)
    plt.plot(len(x) - 1, x[-1], color="r", marker="o")
    # Remove the Y axis
    for k, v in ax.spines.items():
        v.set_visible(False)
    ax.set_xticks([])
    ax.set_yticks([])
    ax.axhline(c="k", linewidth=4, linestyle=(0, (5, 2, 1, 2)))
    # Save the resulting bmp file to the images directory
    plt.savefig(os.path.join(picdir, "spark.png"), dpi=17)
    imgspk = Image.open(os.path.join(picdir, "spark.png"))
    file_out = os.path.join(picdir, "spark.bmp")
    imgspk.save(file_out)
    plt.close(fig)
    plt.cla()  # Close plot to prevent memory error
    ax.cla()  # Close axis to prevent memory error
    imgspk.close()
    return


def custom_format_currency(value, currency, locale):
    value = decimal.Decimal(value)
    locale = Locale.parse(locale)
    pattern = locale.currency_formats["standard"]
    force_frac = (0, 0) if value == int(value) else None
    return pattern.apply(value, locale, currency=currency, force_frac=force_frac)


def updateDisplay(config, pricestack, other):
    """
    Takes the price data, the desired coin/fiat combo along with the config info for formatting
    if config is re-written following adustment we could avoid passing the last two arguments as
    they will just be the first two items of their string in config
    """
    with open(configfile) as f:
        originalconfig = yaml.load(f, Loader=yaml.FullLoader)
    originalcoin = originalconfig["ticker"]["currency"]
    originalcoin_list = originalcoin.split(",")
    originalcoin_list = [x.strip(" ") for x in originalcoin_list]
    whichcoin, fiat = configtocoinandfiat(config)
    days_ago = int(config["ticker"]["sparklinedays"])
    pricenow = pricestack[-1]
    if config["display"]["inverted"] == True:
        currencythumbnail = "currency/" + whichcoin + "INV.bmp"
    else:
        currencythumbnail = "currency/" + whichcoin + ".bmp"
    tokenfilename = os.path.join(picdir, currencythumbnail)
    sparkbitmap = Image.open(os.path.join(picdir, "spark.bmp"))
    ATHbitmap = Image.open(os.path.join(picdir, "ATH.bmp"))
    #   Check for token image, if there isn't one, get on off coingecko, resize it and pop it on a white background
    if os.path.isfile(tokenfilename):
        logging.debug("Getting token Image from Image directory")
        tokenimage = Image.open(tokenfilename).convert("RGBA")
    else:
        logging.debug("Getting token Image from Coingecko")
        tokenimageurl = (
            "https://api.coingecko.com/api/v3/coins/"
            + whichcoin
            + "?tickers=false&market_data=false&community_data=false&developer_data=false&sparkline=false"
        )
        rawimage = requests.get(tokenimageurl, headers=headers).json()
        tokenimage = Image.open(
            requests.get(rawimage["image"]["large"], headers=headers, stream=True).raw
        ).convert("RGBA")
        resize = 100, 100
        tokenimage.thumbnail(resize, Image.BICUBIC)
        # If inverted is true, invert the token symbol before placing if on the white BG so that it is uninverted at the end - this will make things more
        # legible on a black display
        if config["display"]["inverted"] == True:
            # PIL doesnt like to invert binary images, so convert to RGB, invert and then convert back to RGBA
            tokenimage = ImageOps.invert(tokenimage.convert("RGB"))
            tokenimage = tokenimage.convert("RGBA")
        # Create a white rgba background with a 10 pixel border
        new_image = Image.new("RGBA", (120, 120), "WHITE")
        new_image.paste(tokenimage, (10, 10), tokenimage)
        tokenimage = new_image
        tokenimage.thumbnail((100, 100), Image.BICUBIC)
        tokenimage.save(tokenfilename)
    pricechangeraw = round((pricestack[-1] - pricestack[0]) / pricestack[-1] * 100, 2)
    if pricechangeraw >= 10:
        pricechange = str("%+d" % pricechangeraw) + "%"
    else:
        pricechange = str("%+.2f" % pricechangeraw) + "%"
    if "24h" in config["display"] and config["display"]["24h"]:
        timestamp = str(time.strftime("%-H:%M, %d %b %Y"))
    else:
        timestamp = str(time.strftime("%-I:%M %p, %d %b %Y"))
    # This is where a locale change can be made
    if "locale" in config["display"]:
        localetag = config["display"]["locale"]
    else:
        # This is a way of forcing the locale currency info eg 'de_DE' for German formatting
        localetag = "en_US"
    fontreduce = 0  # This is an adjustment that needs to be applied to coins with very low fiat value per coin
    fiatupper = fiat.upper()
    if fiat.upper() == "USDT":
        fiatupper = "USD"
    if fiat.upper() == "BTC":
        fiatupper = "₿"
    if pricenow > 10000:
        # round to nearest whole unit of currency, this is an ugly hack for now
        pricestring = custom_format_currency(int(pricenow), fiatupper, localetag)
    elif pricenow > 0.01:
        pricestring = format_currency(
            pricenow, fiatupper, locale=localetag, decimal_quantization=False
        )
    else:
        # looks like you have a coin with a tiny value per coin, drop the font size, not ideal but better than just printing SHITCOIN
        pricestring = format_currency(
            pricenow, fiatupper, locale=localetag, decimal_quantization=False
        )
    if len(pricestring) > 9:
        fontreduce = 15

    if config["display"]["orientation"] == 0 or config["display"]["orientation"] == 180:
        # 255: clear the image with white
        image = Image.new("L", (176, 264), 255)
        draw = ImageDraw.Draw(image)
        draw.text((110, 80), str(days_ago) + "day :", font=font_date, fill=0)
        draw.text((110, 95), pricechange, font=font_date, fill=0)
        writewrappedlines(
            image, pricestring, 40 - fontreduce, 65, 8, 15, "IBMPlexSans-Medium"
        )
        draw.text((10, 10), timestamp, font=font_date, fill=0)
        image.paste(tokenimage, (10, 25))
        image.paste(sparkbitmap, (10, 125))
        if config["display"]["orientation"] == 180:
            image = image.rotate(180, expand=True)
    if (
        config["display"]["orientation"] == 90
        or config["display"]["orientation"] == 270
    ):
        # 255: clear the image with white
        image = Image.new("L", (264, 176), 255)
        draw = ImageDraw.Draw(image)
        if other["ATH"] == True:
            image.paste(ATHbitmap, (205, 75))
        draw.text(
            (110, 90), str(days_ago) + " day : " + pricechange, font=font_date, fill=0
        )
        if "showvolume" in config["display"] and config["display"]["showvolume"]:
            draw.text(
                (110, 105),
                "24h vol : " + human_format(other["volume"]),
                font=font_date,
                fill=0,
            )
        writewrappedlines(
            image, pricestring, 50 - fontreduce, 50, 8, 15, "IBMPlexSans-Medium"
        )
        image.paste(sparkbitmap, (80, 40))
        image.paste(tokenimage, (0, 10))
        # Don't show rank for #1 coin, #1 doesn't need to show off
        if (
            "showrank" in config["display"]
            and config["display"]["showrank"]
            and other["market_cap_rank"] > 1
        ):
            draw.text(
                (10, 105),
                "Rank: " + str("%d" % other["market_cap_rank"]),
                font=font_date,
                fill=0,
            )
        if (config["display"]["trendingmode"] == True) and not (
            str(whichcoin) in originalcoin_list
        ):
            draw.text((95, 28), whichcoin, font=font_date, fill=0)
        #       draw.text((5,110),"In retrospect, it was inevitable",font =font_date,fill = 0)
        draw.text((95, 15), timestamp, font=font_date, fill=0)
        if config["ticker"]["exchange"] != "default":
            draw.text((95, 30), config["ticker"]["exchange"], font=font_date, fill=0)
        if config["display"]["orientation"] == 270:
            image = image.rotate(180, expand=True)
    #       This is a hack to deal with the mirroring that goes on in older waveshare libraries Uncomment line below if needed
    #       image = ImageOps.mirror(image)
    #   If the display is inverted, invert the image usinng ImageOps
    if config["display"]["inverted"] == True:
        image = ImageOps.invert(image)
    #   Return the ticker image
    return image


def currencystringtolist(currstring):
    # Takes the string for currencies in the config.yaml file and turns it into a list
    curr_list = currstring.split(",")
    curr_list = [x.strip(" ") for x in curr_list]
    return curr_list


def currencycycle(curr_string):
    curr_list = currencystringtolist(curr_string)
    # Rotate the array of currencies from config.... [a b c] becomes [b c a]
    curr_list = curr_list[1:] + curr_list[:1]
    return curr_list


def display_image(img):
    epd = epd2in7.EPD()
    # Also change to V2 if using a V2 screen
    epd.Init_4Gray()
    epd.display_4Gray(epd.getbuffer_4Gray(img))
    epd.sleep()
    thekeys = initkeys()
    #   Have to remove and add key events to make them work again
    removekeyevent(thekeys)
    addkeyevent(thekeys)
    logging.info("Sent image to screen")
    return


def initkeys():
    key1 = 5
    key2 = 6
    key3 = 13
    key4 = 19
    logging.debug("Setup GPIO keys")
    GPIO.setmode(GPIO.BCM)
    GPIO.setup(key1, GPIO.IN, pull_up_down=GPIO.PUD_UP)
    GPIO.setup(key2, GPIO.IN, pull_up_down=GPIO.PUD_UP)
    GPIO.setup(key3, GPIO.IN, pull_up_down=GPIO.PUD_UP)
    GPIO.setup(key4, GPIO.IN, pull_up_down=GPIO.PUD_UP)
    thekeys = [key1, key2, key3, key4]
    return thekeys


def addkeyevent(thekeys):
    #   Add keypress events
    logging.debug("Add key events")
    btime = 500
    GPIO.add_event_detect(thekeys[0], GPIO.FALLING, callback=keypress, bouncetime=btime)
    GPIO.add_event_detect(thekeys[1], GPIO.FALLING, callback=keypress, bouncetime=btime)
    GPIO.add_event_detect(thekeys[2], GPIO.FALLING, callback=keypress, bouncetime=btime)
    GPIO.add_event_detect(thekeys[3], GPIO.FALLING, callback=keypress, bouncetime=btime)
    return


def removekeyevent(thekeys):
    #   Remove keypress events
    logging.debug("Remove key events")
    GPIO.remove_event_detect(thekeys[0])
    GPIO.remove_event_detect(thekeys[1])
    GPIO.remove_event_detect(thekeys[2])
    GPIO.remove_event_detect(thekeys[3])
    return


def keypress(channel):
    global button_pressed
    with open(configfile) as f:
        config = yaml.load(f, Loader=yaml.FullLoader)
    lastcoinfetch = time.time()
    if channel == 5 and button_pressed == 0:
        logging.info("Cycle currencies")
        button_pressed = 1
        crypto_list = currencycycle(config["ticker"]["currency"])
        config["ticker"]["currency"] = ",".join(crypto_list)
        lastcoinfetch = fullupdate(config, lastcoinfetch)
        configwrite(config)
        return
    elif channel == 6 and button_pressed == 0:
        logging.info("Rotate - 90")
        button_pressed = 1
        config["display"]["orientation"] = (config["display"]["orientation"] + 90) % 360
        lastcoinfetch = fullupdate(config, lastcoinfetch)
        configwrite(config)
        return
    elif channel == 13 and button_pressed == 0:
        logging.info("Invert Display")
        button_pressed = 1
        config["display"]["inverted"] = not config["display"]["inverted"]
        lastcoinfetch = fullupdate(config, lastcoinfetch)
        configwrite(config)
        return
    elif channel == 19 and button_pressed == 0:
        logging.info("Cycle fiat")
        button_pressed = 1
        fiat_list = currencycycle(config["ticker"]["fiatcurrency"])
        config["ticker"]["fiatcurrency"] = ",".join(fiat_list)
        lastcoinfetch = fullupdate(config, lastcoinfetch)
        configwrite(config)
        return
    return


def configwrite(config):
    """
    Write the config file following an adjustment made using the buttons
    This is so that the unit returns to its last state after it has been
    powered off
    """
    with open(configfile, "w") as f:
        data = yaml.dump(config, f)
    #   Reset button pressed state after config is written
    global button_pressed
    button_pressed = 0
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

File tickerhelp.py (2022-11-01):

#!/usr/bin/python3
#	tickerhelper: Give it a string of symbols and it returns the coingeck IDs
#   This is to address the issue that some of the coingecko IDs are not intuitive
#   tickerhelp.py -s "xmr, dot, avax"
#   will give
#   Symbol=  xmr ID=  monero
#   Symbol=  dot ID=  polkadot
#   Symbol=  AVAX ID=  avalanche-2



import requests
import sys, getopt

def symboltoid(code,melist):
	lowercode=code.lower()
	uppercode=code.upper()
	for i in range (len(melist)):
		target=melist[i]['symbol']
		idstring="I cannot find it, please don't hate me"
		if target==lowercode or target==uppercode:
			theindex=i
			idstring=melist[i]['id']
			if "peg" not in idstring:
				print("Symbol= ",code,"ID= ",idstring)
	return idstring

def main():
	try:
		options, remainder = getopt.getopt(sys.argv[1:], 's:', ['symbol='])
#
	except getopt.GetoptError:
		print ('tickerhelp.py -s <symbollist>')
		sys.exit(2)

	for opt, arg in options:
		if opt == '-h':
			print ('tickerhelp.py -s <symbollist>')
			sys.exit()
		elif opt in ("-s", "--symbol"):
			symbollist = arg.split(",")
	coinlisturl="https://api.coingecko.com/api/v3/coins/list"
	melist=requests.get(coinlisturl).json()
	for i in range(len(symbollist)):
		symbol=symbollist[i].strip()
		symboltoid(symbol,melist)

if __name__ == '__main__':
	main()

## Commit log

2020-11-30 fixed paths for when the script is ran from another diretory
    [btcticker.py]
2020-11-30 added frames directory
2020-12-02 Broke up updateDisplay into a more sensible structure
    [btcticker.py]
2020-12-02 Belt and braces
2020-12-02 Fix updateDisplay call
    Function call did not pass pricestack var on line 268 and would cause an error and a crash
    [btcticker.py]
2020-12-02 Moved BTC Logo in vertical
    BTC Logo in vertical mode clipped the text by a couple pixels. Moved it down by 5.
2020-12-02 The initial run would crash if the internet wasn't available
    [btcticker.py]
2020-12-04 Corrected config file location
    [btcticker.py]
2020-12-04 Button 1 toggles between cryptocurrencies listed in config.yaml. Currently only Bitcoin and Ethereum Coingecko is now the backup for Coinapi
2020-12-04 Button 1 toggles between cryptocurrencies listed in config.yaml
2020-12-06 Buttons overview
2020-12-07 Basic Frame.
    Buttons are no longer accessible when using this minimal frame
    [Frame v5.stl]
2020-12-08 Frame 5
2020-12-12 Broader fallbaback if coingecko won't play
    [btcticker.py]
2020-12-19 Swapped hide mode button for toggle fiat
    [btcticker.py]
2021-01-03 info on api error
    [btcticker.py]
2021-01-03 Memory issue in plot loop
    [btcticker.py]
2021-01-05 slight change to logic to prevent sys exit
    [btcticker.py]
2021-01-05 slight change to logic to prevent sys exit on failed data pull
    [btcticker.py]
2021-01-12 fixed double rounding that made high freq pulls an issue
    [btcticker.py]
2021-01-20 ATH workaround for non-default exchanges
    [btcticker.py]
2021-01-28 added cny symbol workaround
    [btcticker.py]
2021-02-11 Basic Frame w/ no screws
    Closed over the screw holes and added pegs so that the frame can be friction fitted. Slightly modified the frame opening to better fit my Waveshare e-Paper hat.
    [Frame v6.stl]
2021-02-13 added cla to ax to prevent memory error
    [btcticker.py]
2021-02-28 Added GPIO cleanup to interrupt
2021-02-28 Bug in GPIO setup
    [btcticker.py]
2021-03-02 Transparency masks on some tokens were a problem
    [btcticker.py]
2021-03-24 Errors on close fixed
    [btcticker.py]
2021-04-14 error handling - delay tim 20s
    [btcticker.py]
2021-06-14 Minor stability improvement
    - Remove debug level logging by default
    - Add general exception screen print
    - Add line numbers to beanaproblem calls
    [btcticker.py]
2021-06-14 Flip ticker & current price lookups
    - Flip ticker & current price lookup so current price is the most up-to-date
    - Reduce sleep from 5 to 1 second
    [btcticker.py]
2021-08-10 remove gpio polling in while loop (drastically reduces cpu load on my pi zero) add gpio event detect https://tieske.github.io/rpi-gpio/modules/GPIO.html#add_event_detect ensure only 1 button function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
2021-08-22 Fixes #77 Close the fig subplot to prevent memory leak warning message from matplotlib
    [btcticker.py]
2021-10-04 Workaround to keep buttons working after display sleep. Should fix https://github.com/llvllch/btcticker/issues/82
    Hopefully fixed upstream https://github.com/waveshare/e-Paper/pull/189
    [btcticker.py]
2021-12-27 Checks upper and lower case
2022-02-05 switched to Babel for number formatting
2022-02-06 Update requirements.txt
    The current requirements are missing nh-currency==1.0.1
    https://github.com/veebch/btcticker/issues/89 even says it is required.
2022-04-20 Error message on epaper
    [btcticker.py]
2026-08-17 Fix background color flicker when inverted is false
    Fixes #139
    [btcticker.py]

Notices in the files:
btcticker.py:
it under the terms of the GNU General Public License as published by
